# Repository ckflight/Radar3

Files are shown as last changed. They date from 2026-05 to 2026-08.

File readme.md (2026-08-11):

# FMCW3 Hardware Design

Custom 6-layer FPGA-based FMCW radar platform designed in KiCad for high-speed radar acquisition, RF processing, and FPGA DSP applications.

The project integrates:

- RF transmitter and dual receiver chains
- ADL5802 mixer stage
- ADA4940 IF signal conditioning
- LTC2292 high-speed ADC
- Artix-7 FPGA processing
- FT2232H USB FIFO streaming
- Multi-rail low-noise power architecture









---

# Overview

FMCW3 is a custom 5.8 GHz FMCW radar hardware platform built around the Xilinx XC7A35T Artix-7 FPGA.

The board is designed for:

- FMCW radar experiments
- SAR imaging
- Doppler processing
- Phase analysis
- FPGA DSP development
- Radar algorithm research

---

# Main Features

## FPGA

- Xilinx XC7A35T-FTG256
- MicroBlaze soft-core support
- SPI Flash boot
- JTAG debugging
- SD card support
- Parallel ADC interface

## RF Front-End

- HMC431LP4 VCO
- Dual RX channels
- ADL5802 active mixer
- Differential IF architecture
- ADA4940 differential amplifiers

## ADC

- LTC2292 dual-channel ADC
- 12-bit parallel interface
- Differential analog inputs
- FPGA synchronous acquisition

## USB

- FT2232H
- FT245 synchronous FIFO mode
- USB Type-C
- High-speed radar data streaming

---

# 6-Layer PCB Design

The board is designed as a controlled impedance 6-layer RF PCB.

## RF Transmission Line Rules

### Single-Ended 50Ω

- JLCPCB:
  - 0.156 mm trace width
- CST Simulation:
  - 0.17 mm trace width

### Differential 50Ω

- 0.4 mm differential pair width/spacing

### USB Differential Pair

- Target impedance:
  - 90Ω differential
- 0.23 mm width
- 0.13 mm spacing

Results:
- ~100Ω on Oshpark
- ~85Ω on JLCPCB

Accepted as operational for USB HS routing.

---

# RF Layout Notes

- Ground pour kept at least:
  - 3× substrate height away from RF traces
- Via stitching placed:
  - ~1 mm beside RF traces
  - ~0.6 mm from trace edge
- LO path uses smooth bends for impedance continuity
- ADC and IF lengths matched for improved phase consistency
- RF clearances and differential routing optimized
- Differential RF routing corrected for proper 50Ω behavior

---

# KiCad Project Structure

```text
FMCW3/
├── fpga.kicad_sch
├── adc.kicad_sch
├── usb.kicad_sch
├── power.kicad_sch
├── mixer.kicad_sch
├── if.kicad_sch
├── tx.kicad_sch
├── rx.kicad_sch
├── fmcw3.kicad_sch
├── fmcw3.kicad_pcb
└── README.md
```

---

# Design Targets

| Parameter | Value |
|---|---|
| Radar Type | FMCW |
| Frequency | 5.8 GHz |
| FPGA | XC7A35T |
| ADC | LTC2292 |
| Mixer | ADL5802 |
| IF Amplifier | ADA4940 |
| USB Interface | FT2232H |
| PCB Stackup | 6 Layer |
| CAD Tool | KiCad 9 |

---

# Related Repositories

FPGA Firmware:
https://github.com/ckflight/FMCW3

Radar Software:
https://github.com/ckflight/FMCW_RADAR

https://github.com/ckflight/FMCW_RADAR_2v2

AI Radar Experiments:
https://github.com/ckflight/RADAR_24GHZ_NEURAL_NETWORK

---

# Author

Cenk KESKİN

---

# License

This project is licensed under the GNU General Public License v3.0 (GPLv3).

You are free to use, modify, and distribute this software under the terms of the GPLv3 license.

Any distributed modifications or derivative works must also be released under the same license and include source code.

For full license text:

https://www.gnu.org/licenses/gpl-3.0.html

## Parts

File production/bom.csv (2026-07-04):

Designator | Footprint | Quantity | Value | LCSC Part #
C1, C108, C115, C116, C120, C121, C122, C123, C15, C152, C153, C154, C158, C159, C160, C161, C17, C18, C2, C207, C21, C210, C211, C212, C219, C221, C223, C224, C225, C23, C24, C25, C252, C27, C30, C301, C302, C4, C41, C43, C49, C58, C6, C63, C73, C74, C75 | SMD_0402 | 47 | 100n
C10, C13, C36 | SMD_0402 | 3 | 2.2n
C100, C101, C102, C106, C162, C248, C26, C303, C306, C60, C61, C62, C64, C70, C71, C76, C77, C78, C79, C80, C81, C82, C83, C84, C85, C86, C87, C88, C93, C94, C98 | SMD_0805 | 31 | 10u
C103, C104, C32 | SMD_0805 | 3 | DNP
C109, C11, C110, C111, C112, C113, C114, C3, C300, C44, C5, C53, C7, C8 | SMD_0402 | 14 | 10p
C117, C118, C119, C163, C164, C165, C166, C167, C168, C180, C213 | SMD_0402 | 11 | 100p
C12, C19, C20, C217, C218, C222, C249, C89 | SMD_0603 | 8 | 1u
C14, C304, C305, C307 | SMD_0402 | 4 | 220p
C155, C156, C157, C183, C185, C186, C188, C194, C195 | SMD_0603 | 9 | 4.7u
C16, C179, C206, C28, C37, C38, C9, C95 | SMD_0402 | 8 | 10n
C170, C171, C187, C189, C190, C191, C192, C193, C197, C198, C199, C200, C201, C202, C203, C204, C205, C250, C251, C96, C97, C99 | SMD_0402 | 22 | 470n
C181 | SMD_1210 | 1 | 100u
C182, C184, C196 | SMD_1206 | 3 | 47u
C208, C209 | SMD_0402 | 2 | 15p
C216, C22, C220, C31 | SMD_0603 | 4 | 2.2u
C29, R10, R50, R69 | SMD_0402 | 4 | DNP
C33, C34, C39, C40 | SMD_0402 | 4 | 5p
C42, C46, C52, C55 | SMD_0402 | 4 | 18p
C48, C57 | SMD_0402 | 2 | 0.5p
CON1 | DM3BT-DSF-PEJS | 1 | SD_Card_DM3BT
CON2 | BarrelJack | 1 | BARREL_JACK
D1, D2, D3, D5, D6, D7 | Diode_0603 | 6 | LED
F1, F2 | RF_via | 2 | Via
FB1, FB12, FB13, FB14, FB2, FB3, FB4, FB5, FB6, FB7, FB8 | SMD_0603 | 11 | BLM18PG181SN1D
FB11 | SMD_0805 | 1 | MPZ2012S101AT000
J1 | USB_C_Receptacle_GCT_USB4105-xx-A_16P_TopMnt_Horizontal | 1 | USB_C_Receptacle_USB2.0
J2 | PinHeader_2x8_P2.5mm | 1 | Connector_02x08
L1, L3 | SMD_0402 | 2 | LQW15AN9N9J80D
L12, L13, L14, L15 | SMD_0805 | 4 | 2.2u
L2, L4 | SMD_0402 | 2 | 0.6n
L5, L6, L7 | SRR6040A | 3 | 33u (SRR6040A-330M)
P1, P2, U15 | CONSMA003.062 | 3 | SMA
P5, P7, P8 | MountingHole_3.2mm_M3_Pad_Via_mod | 3 | CONN_01X01
R1 | SMD_0402 | 1 | 5.49k
R100, R17, R51, R52, R53, R54, R97, R98, R99 | SMD_0402 | 9 | 49.9
R104, R29, R30, R39, R40, R73, R83, R92 | SMD_0402 | 8 | 10k
R109, R111, R24, R25, R27, R300, R301, R4, R72 | SMD_0402 | 9 | 1k
R11, R12, R9 | SMD_0402 | 3 | 16.9
R110, R114, R115, R18, R19, R20, R41, R42, R55, R56, R57, R58, R63, R64, R7, R70, R80, R81, R93 | SMD_0402 | 19 | 0
R112, R117, R118, R14, R5, R6, R82, R91 | SMD_0402 | 8 | 4.7k
R13, R130, R15, R16, R21, R84, R85, R88 | SMD_0402 | 8 | 33
R2, R48 | SMD_0402 | 2 | 3.3K
R22, R23 | SMD_0402 | 2 | 100
R26, R28, R31, R38 | SMD_0402 | 4 | 500
R3, R8 | SMD_0402 | 2 | 5.1k
R302 | SMD_0402 | 1 | 27
R303, R305 | SMD_0603 | 2 | 2
R304 | SMD_0402 | 1 | 27.4k
R32 | SMD_0402 | 1 | 68k
R33, R34, R36 | SMD_0402 | 3 | 100k
R35, R46, R47 | SMD_0402 | 3 | 18.7K
R37, R71 | SMD_0402 | 2 | 12k
R43 | SMD_0402 | 1 | 18k
R44, R49 | SMD_0402 | 2 | 2k
R45 | SMD_0402 | 1 | 49.9k
R79 | SMD_0402 | 1 | 2.2k
SW1, SW2 | EVP-AWBA2A | 2 | B3U-1000P
U1 | VFQFN-24 | 1 | ADF4158
U10 | VQFN-24 | 1 | HMC431LP4
U11, U16 | XFDFN-6 | 2 | SKY65404
U12 | PAT1220 | 1 | PAT1220-3dB
U13, U9 | DFN-8-1EP_2x2mm_Pitch0.5mm | 2 | TRF37A73
U14 | QFN-20-1EP_4x4mm_P0.5mm_EP2.5x2.5mm_ThermalVias | 1 | TQP5525
U17, U18, U19 | SOT23_6 | 3 | LMR51420
U2, U31, U34, U35, U38, U4, U41, U42, U43, U44, U46, U47, U48, U49, U5 | SolderPad_1_1.0mm_SMD_Circle | 15 | SolderPad_1_Circle
U20, U39 | SOT-23-5 | 2 | LP5907-3.0
U21 | SOT-23-5 | 1 | LP2985A-10DBVR
U22, U23, U24 | DFN-8-1EP_4x4mm_P0.8mm_EP2.3x3.24mm | 3 | LD3920
U25 | DFN-6-1EP_3x3mm_P0.95mm_EP1.7x2.6mm | 1 | LD3920_33
U26, U27, U28 | 5400BL15B050E | 3 | 5400BL15B0050001E
U29 | QFN-24-1EP_4x4mm_Pitch0.5mm | 1 | ADL5802
U3 | PAT1220 | 1 | PAT1220-6dB
U30 | FTG256 | 1 | XC7A35T-1FTG256C
U32 | SOT-23-6 | 1 | 93LC46B
U33 | LQFP-64_10x10mm_Pitch0.5mm | 1 | FT2232H
U36 | SolderPad_1_1.5mm_SMD_Circle | 1 | SolderPad_1_Circle
U40 | DFN-S-8-1EP_6x5mm_Pitch1.27mm | 1 | W25Q128JV
U45 | SSOP16_3.9x4.9mm_P0.635mm | 1 | LT6232
U6 | SOT23_6 | 1 | PL133-37
U7 | SOT-353_SC-70-5 | 1 | TLV172DCK
U8 | QFN-64-1EP_9x9mm_Pitch0.5mm | 1 | LTC2292
Y1 | ABM10 | 1 | ABM10-167-12.000MHZ-T3
Y2 | Oscillator_SMD_ECS_2520MV-xxx-xx-4Pin_2.5x2.0mm | 1 | ECS ECS-TXO-32CSMV-400
Z1 | Directional_Coupler_15dB_0.169mm_v2 | 1 | 15dB COUPLER

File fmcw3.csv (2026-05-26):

Qty | Value | Footprint
49 | 100n | Footprints:SMD_0402
18 | 10p | Footprints:SMD_0402
3 | 2.2n | Footprints:SMD_0402
8 | 1u | Footprints:SMD_0603
4 | 220p | Footprints:SMD_0402
4 | 2.2u | Footprints:SMD_0603
30 | 10u | Footprints:SMD_0805
8 | 10n | Footprints:SMD_0402
30 | DNP | Footprints:SMD_0402
8 | DNP | Footprints:SMD_0603
4 | 18p | Footprints:SMD_0402
2 | 0.5p | Footprints:SMD_0402
13 | DNP | Footprints:SMD_0805
22 | 470n | Footprints:SMD_0402
11 | 100p | Footprints:SMD_0402
9 | 4.7u | Footprints:SMD_0603
1 | 100u | Footprints:SMD_1210
3 | 47u | Footprints:SMD_1206
2 | 15p | Footprints:SMD_0402
1 | SD_Card_DM3BT | fmcw3:DM3BT-DSF-PEJS
1 | BARREL_JACK | Footprints:BarrelJack
6 | LED | Footprints:Diode_0603
11 | BLM18PG181SN1D | Footprints:SMD_0603
1 | MPZ2012S101AT000 | Footprints:SMD_0805
1 | USB_C_Receptacle_USB2.0 | Connector_USB:USB_C_Receptacle_GCT_USB4105-xx-A_16P_TopMnt_Horizontal
2 | LQW15AN9N9J80D | Footprints:SMD_0402
2 | 0.6n | Footprints:SMD_0402
3 | 33u (SRR6040A-330M) | fmcw3:SRR6040A
4 | 2.2u | Footprints:SMD_0805
1 | 5.49k | Footprints:SMD_0402
1 | 3.3K | Footprints:SMD_0402
2 | 5.1k | Footprints:SMD_0402
1 | 1K | Footprints:SMD_0402
8 | 4.7k | Footprints:SMD_0402
16 | 0 | Footprints:SMD_0402
3 | 16.7 | Footprints:SMD_0402
4 | 33 | Footprints:SMD_0402
9 | 49.9 | Footprints:SMD_0402
4 | 22 | Footprints:SMD_0402
2 | 100 | Footprints:SMD_0402
11 | 1k | Footprints:SMD_0402
2 | 68k | Footprints:SMD_0402
3 | 100k | Footprints:SMD_0402
1 | 18.7K | Footprints:SMD_0402
2 | 12k | Footprints:SMD_0402
1 | 18k | Footprints:SMD_0402
2 | 2k | Footprints:SMD_0402
1 | 49.9k | Footprints:SMD_0402
2 | 18.7k | Footprints:SMD_0402
1 | 3.3k | Footprints:SMD_0402
4 | 20.5k | Footprints:SMD_0402
3 | 10k | Footprints:SMD_0402
1 | 2.2k | Footprints:SMD_0402
1 | 240 | Footprints:SMD_0402
1 | 27 | Footprints:SMD_0402
2 | 2 | Footprints:SMD_0603
1 | 27.4k | Footprints:SMD_0402
2 | SW_PUSH | fmcw3:EVP-AWBA2A
1 | ADF4158 | fmcw3:VFQFN-24
1 | PAT1220-6dB | fmcw3:PAT1220
1 | ECS-TXO-3225MV | Oscillator:Oscillator_SMD_EuroQuartz_XO32-4Pin_3.2x2.5mm
1 | NB3N551 | fmcw3:DFN-8
1 | TLV172DCK | TO_SOT_Packages_SMD:SOT-353_SC-70-5
1 | LTC2292 | Housings_DFN_QFN:QFN-64-1EP_9x9mm_Pitch0.5mm
2 | TRF37A73 | fmcw3:DFN-8-1EP_2x2mm_Pitch0.5mm
1 | HMC431LP4 | fmcw3:VQFN-24
2 | SKY65404 | fmcw3:XFDFN-6
1 | PAT1220-3dB | fmcw3:PAT1220
1 | TQP5525 | Package_DFN_QFN:QFN-20-1EP_4x4mm_P0.5mm_EP2.5x2.5mm_ThermalVias
3 | LMR51420 | Footprints:SOT23_6
2 | LP5907-3.0 | fmcw3:SOT-23-5
1 | LP2985A-10DBVR | fmcw3:SOT-23-5
3 | LD3920 | Package_DFN_QFN:DFN-8-1EP_4x4mm_P0.8mm_EP2.3x3.24mm
1 | BU33SD5WG | fmcw3:SOT-23-5
3 | 5400BL15B050E | fmcw3:5400BL15B050E
1 | ADL5802 | Housings_DFN_QFN:QFN-24-1EP_4x4mm_Pitch0.5mm
1 | XC7A35T-1FTG256C | fmcw3:FTG256
1 | 93LC46B | fmcw3:SOT-23-6
1 | FT2232H | Housings_QFP:LQFP-64_10x10mm_Pitch0.5mm
2 | ADA4940-2 | fmcw3:VFQFN-24
1 | W25Q32JV | Housings_DFN_QFN:DFN-S-8-1EP_6x5mm_Pitch1.27mm
1 | ABM10-167-12.000MHZ-T3 | fmcw3:ABM10

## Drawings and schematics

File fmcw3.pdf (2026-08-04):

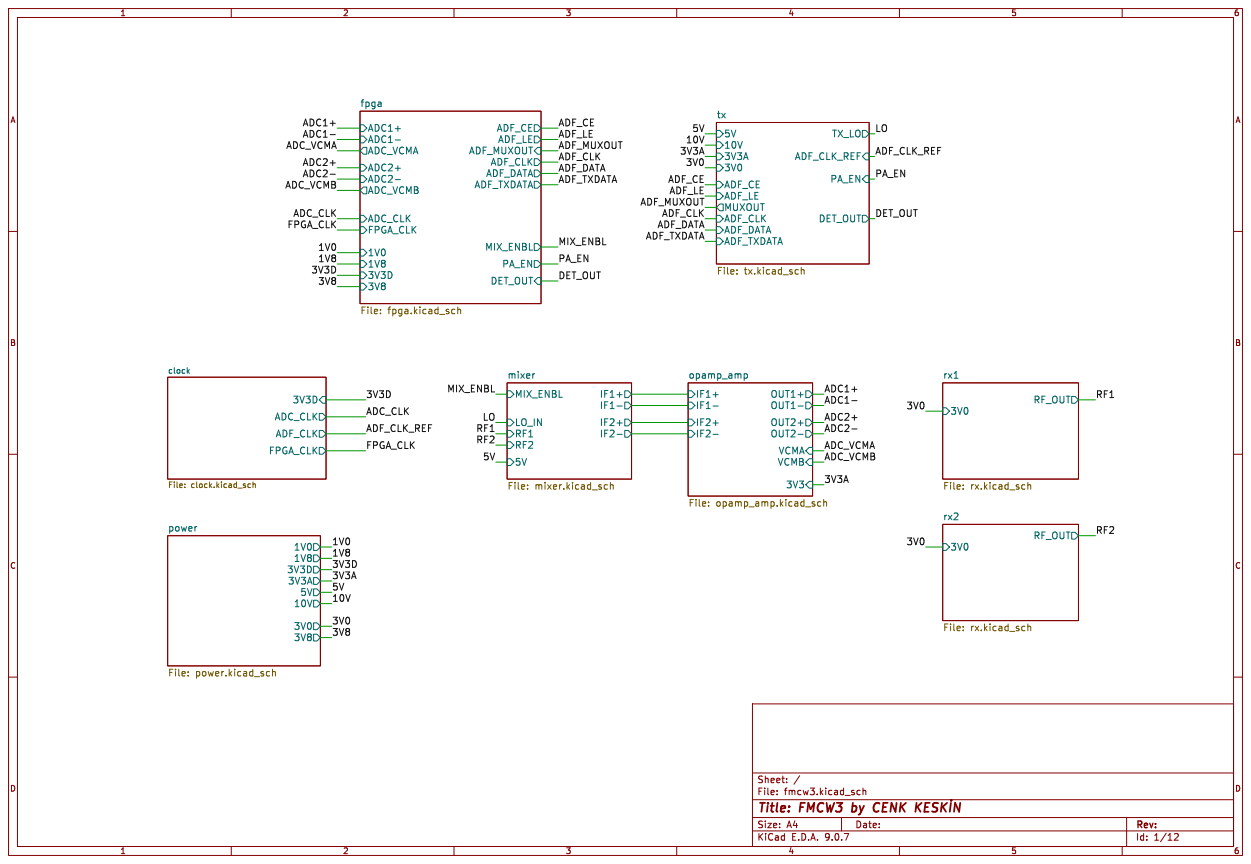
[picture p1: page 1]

File: fmcw3.kicad_sch Sheet: /
Id: 1/12 Title: FMCW3 by CENK þÿKESK0N

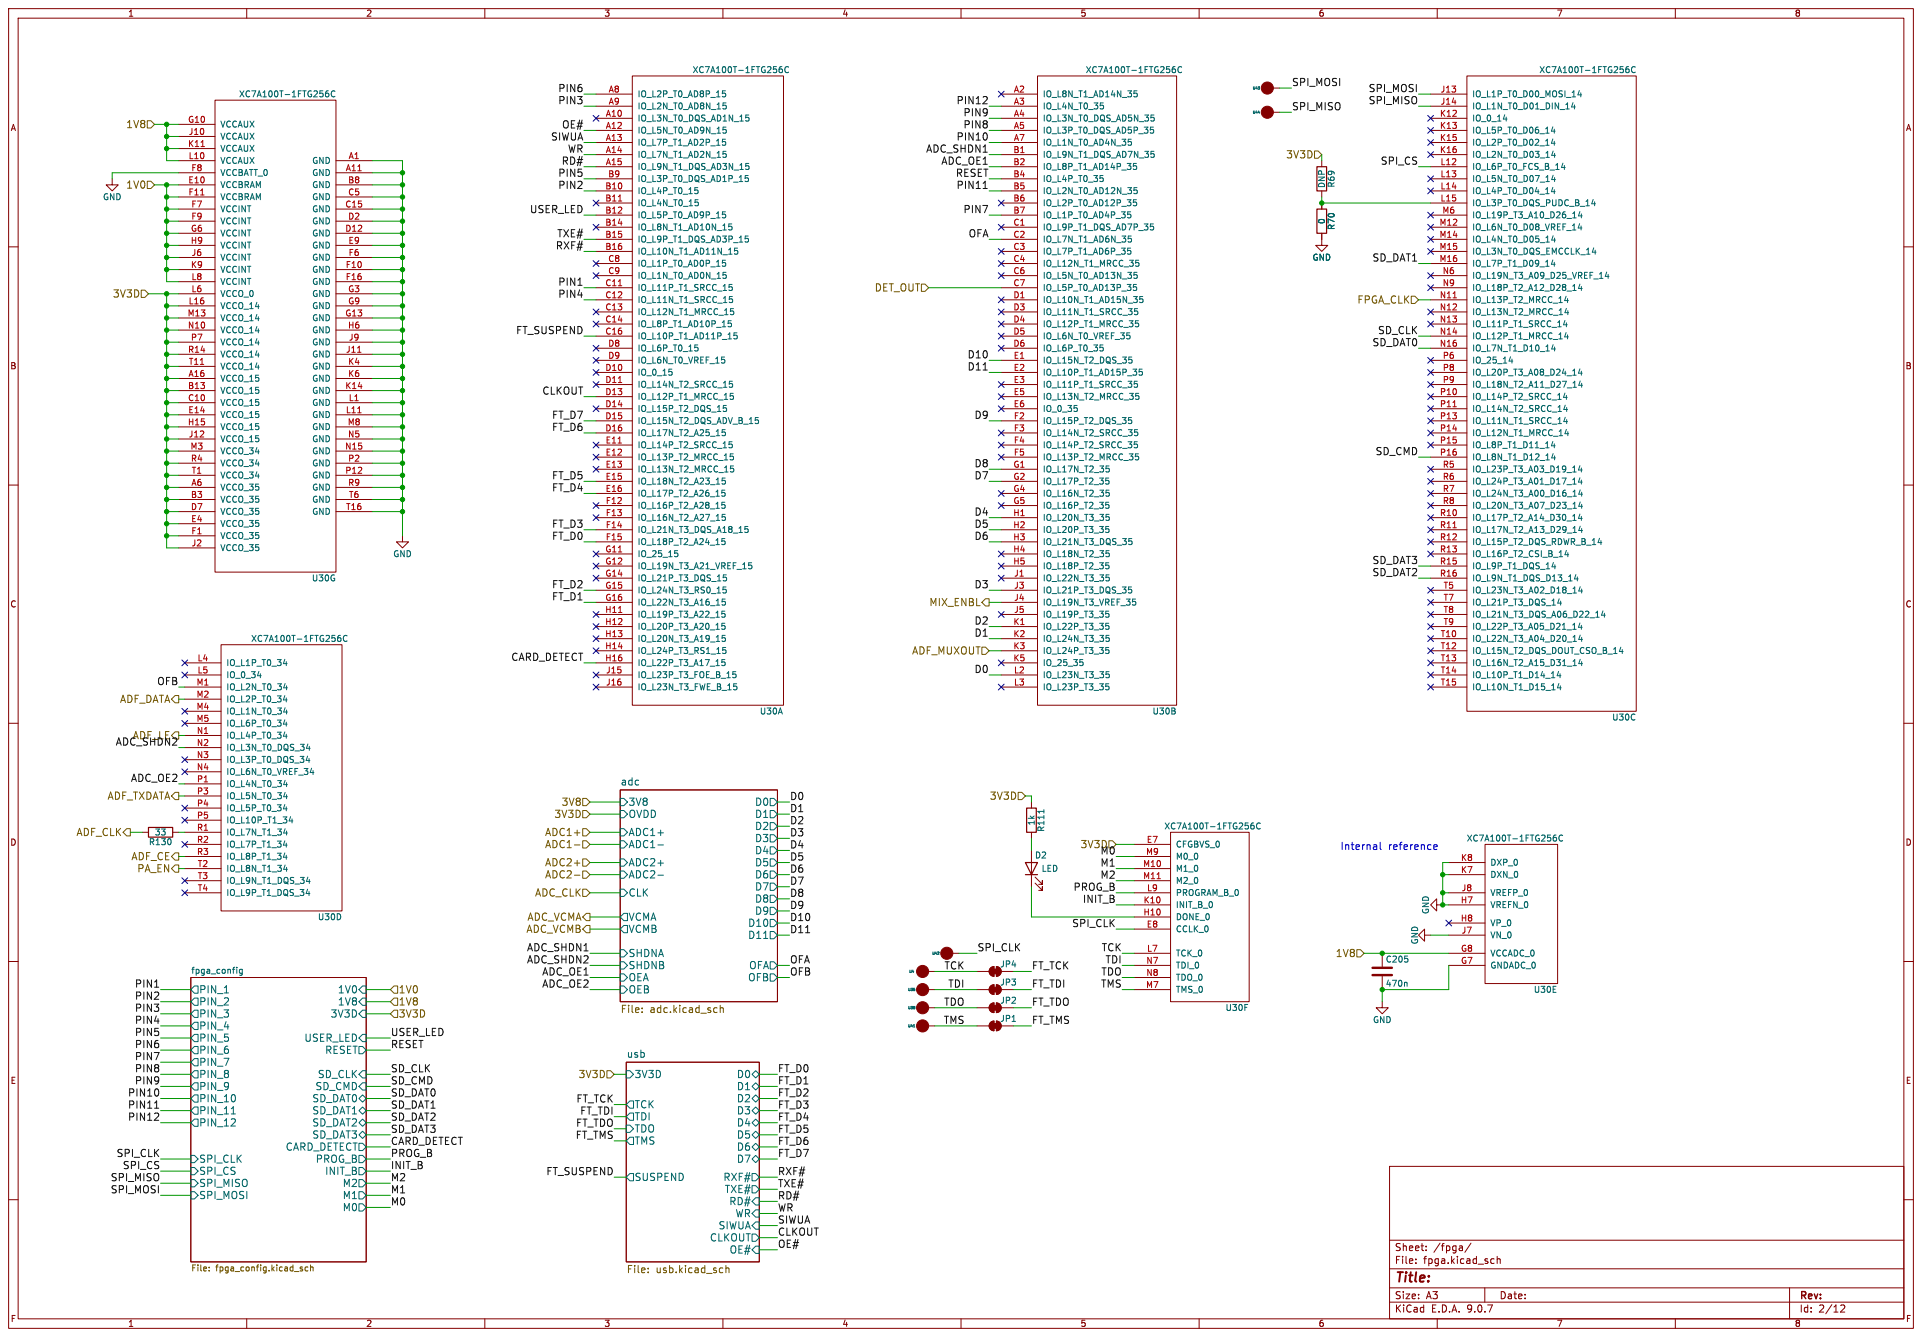
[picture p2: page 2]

PIN3 PIN6 OE# WR
PIN1 PIN4 SIWUA
PIN5 RD# PIN2 TXE# RXF# CLKOUT

SD_DAT3 CARD_DETECT

SIWUA OE#

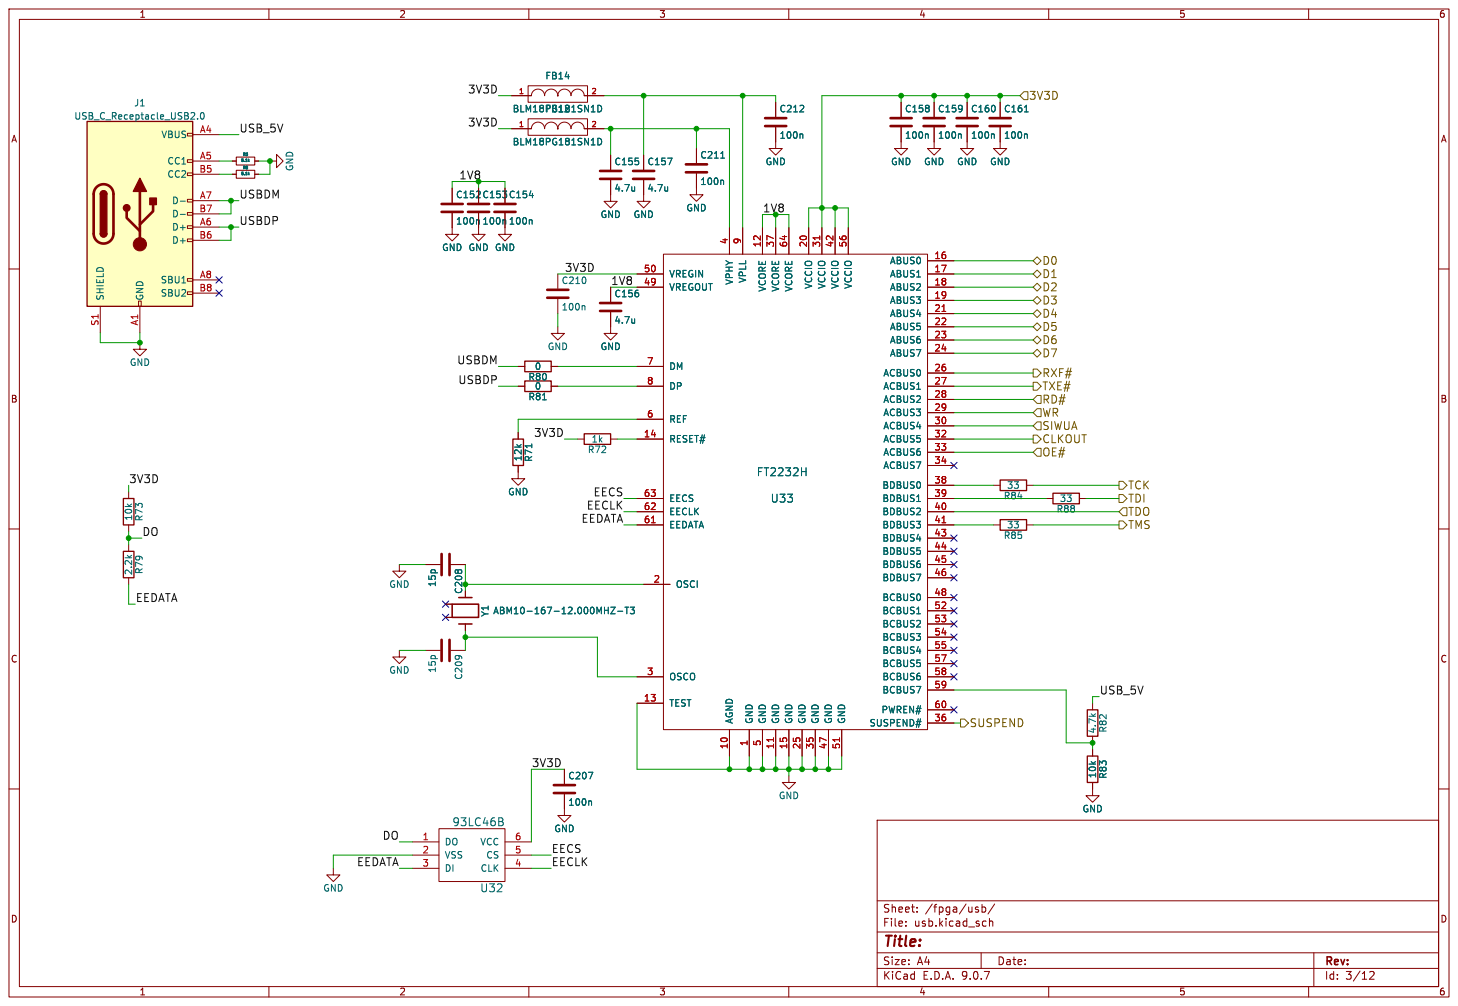
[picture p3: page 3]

Id: 3/12 Title: File: usb.kicad_sch Sheet: /fpga/usb/

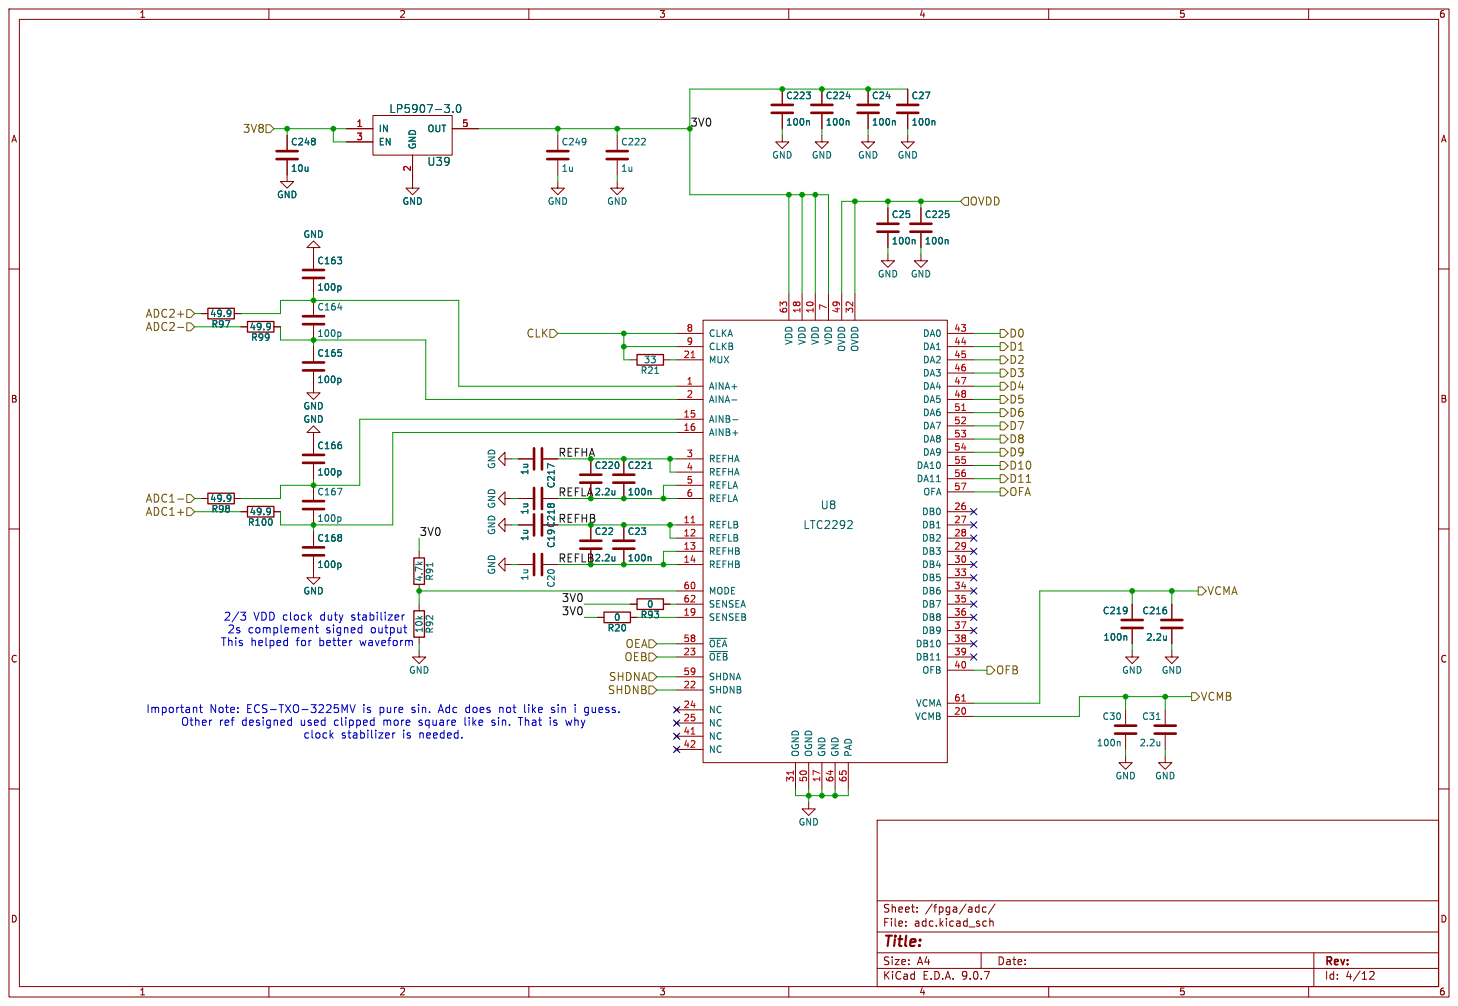
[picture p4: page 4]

7 GND 64 OVDD 49 PAD 65 OVDD 32 DA0 43 DA1 44 DA2 45 DA3 46 DA4 47 DA5 48 DA6 51 DA7 52 DA8 53 DA9 54 DA10 55 DA11 56 OFA 57 DB0 26 DB1 27 DB2 28 DB3 29 DB4 30 DB5 33 DB6 34 DB7 35 DB8 36 DB9 37 DB10 38 DB11 39 OFB 40 VCMA 61 VCMB 20 U8

Other ref designed used clipped more square like sin. That is why

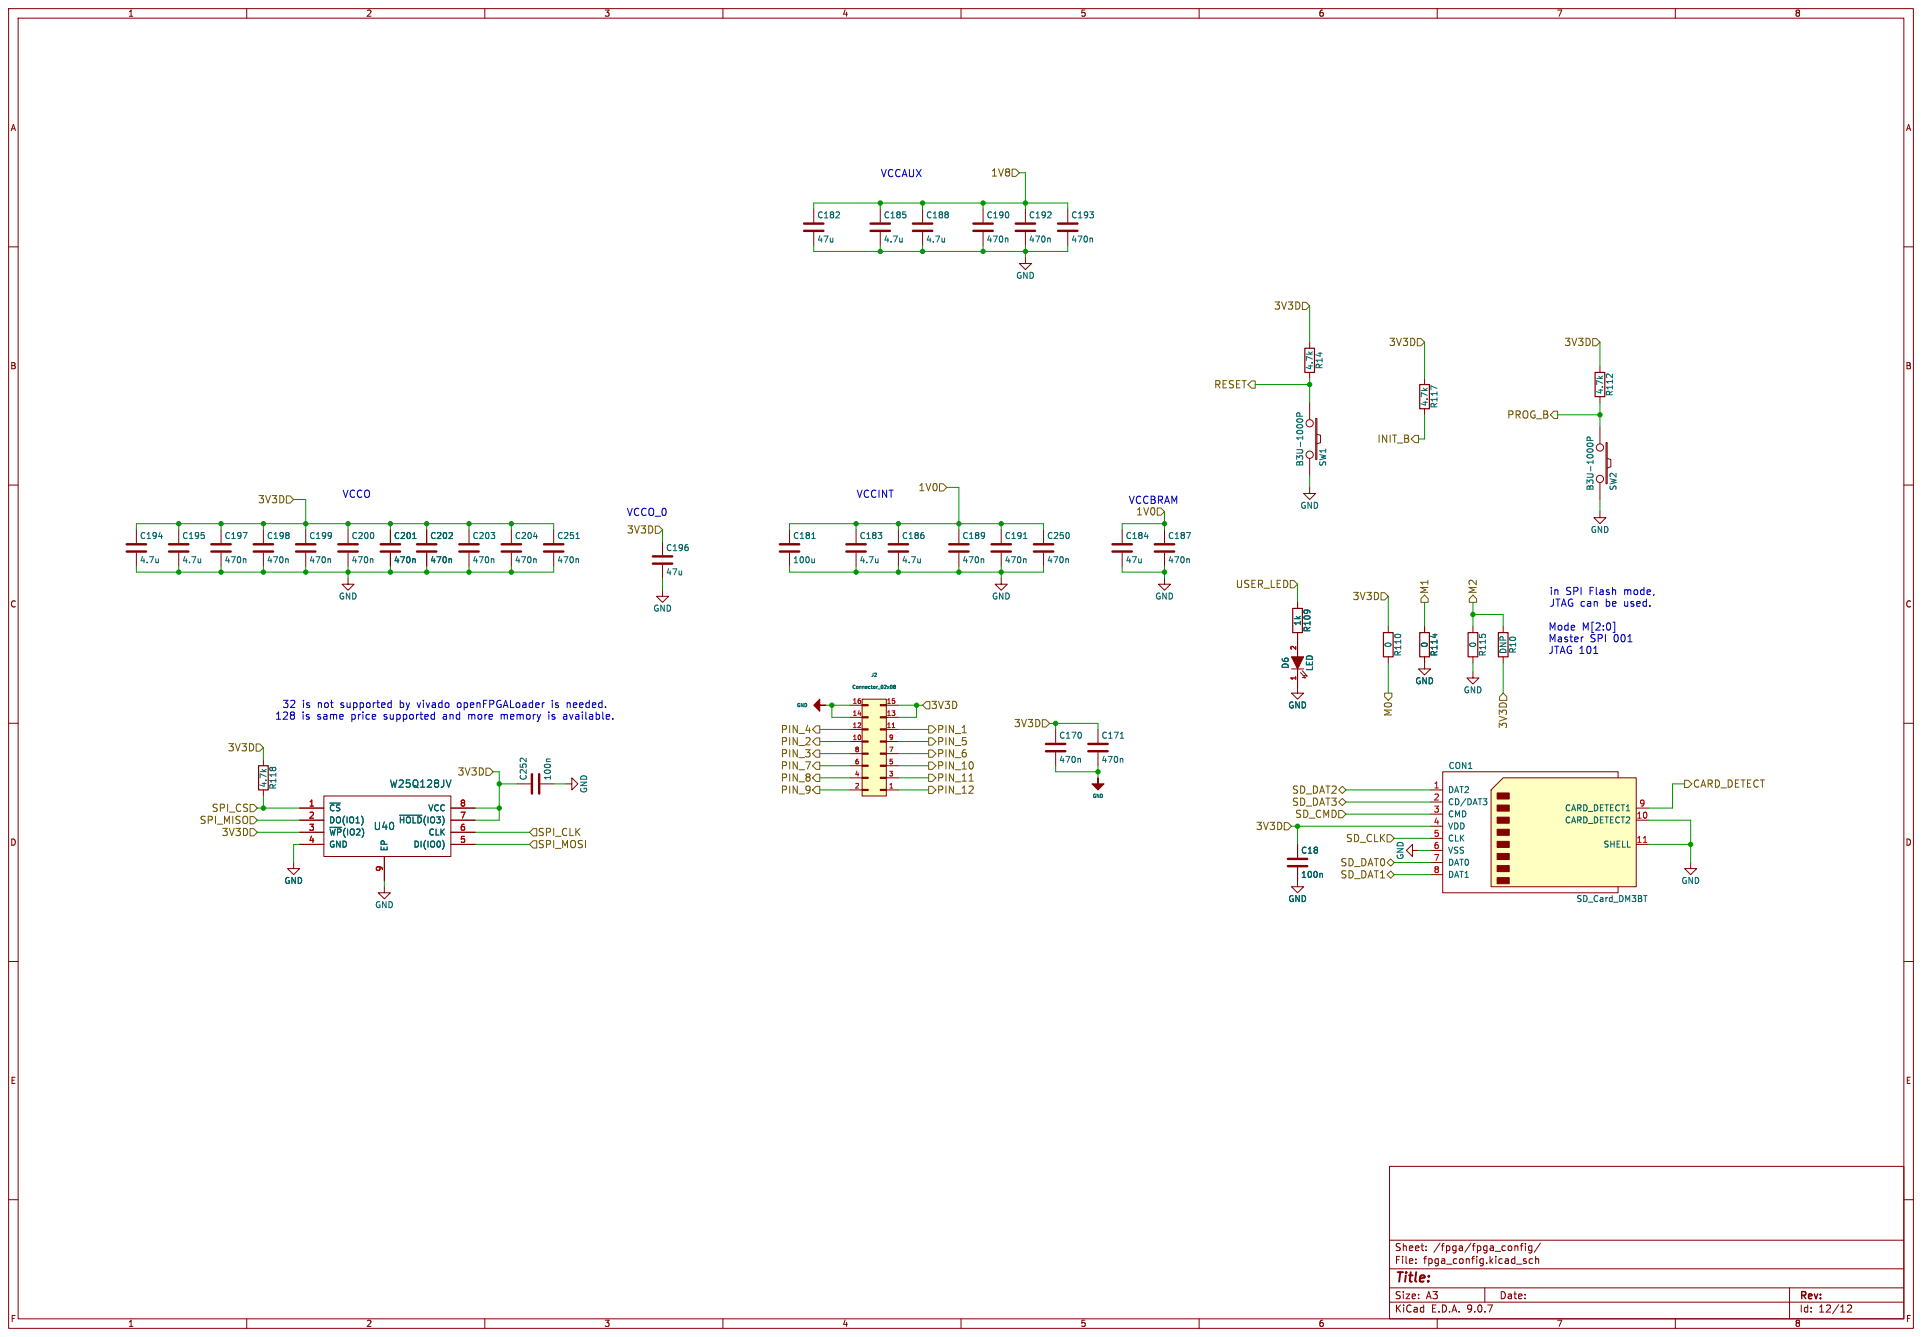
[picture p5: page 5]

9 VCC 8 ~{HOLD}(IO3) 7 CLK 6 DI(IO0) 5 U40W25Q128JV B3U-1000P SW1 GND GND GND

in SPI Flash mode,

9 VCC 8 ~{HOLD}(IO3) 7 CLK 6 DI(IO0) 5 GND

Id: 12/12 Title: File: fpga_config.kicad_sch Sheet: /fpga/fpga_config/

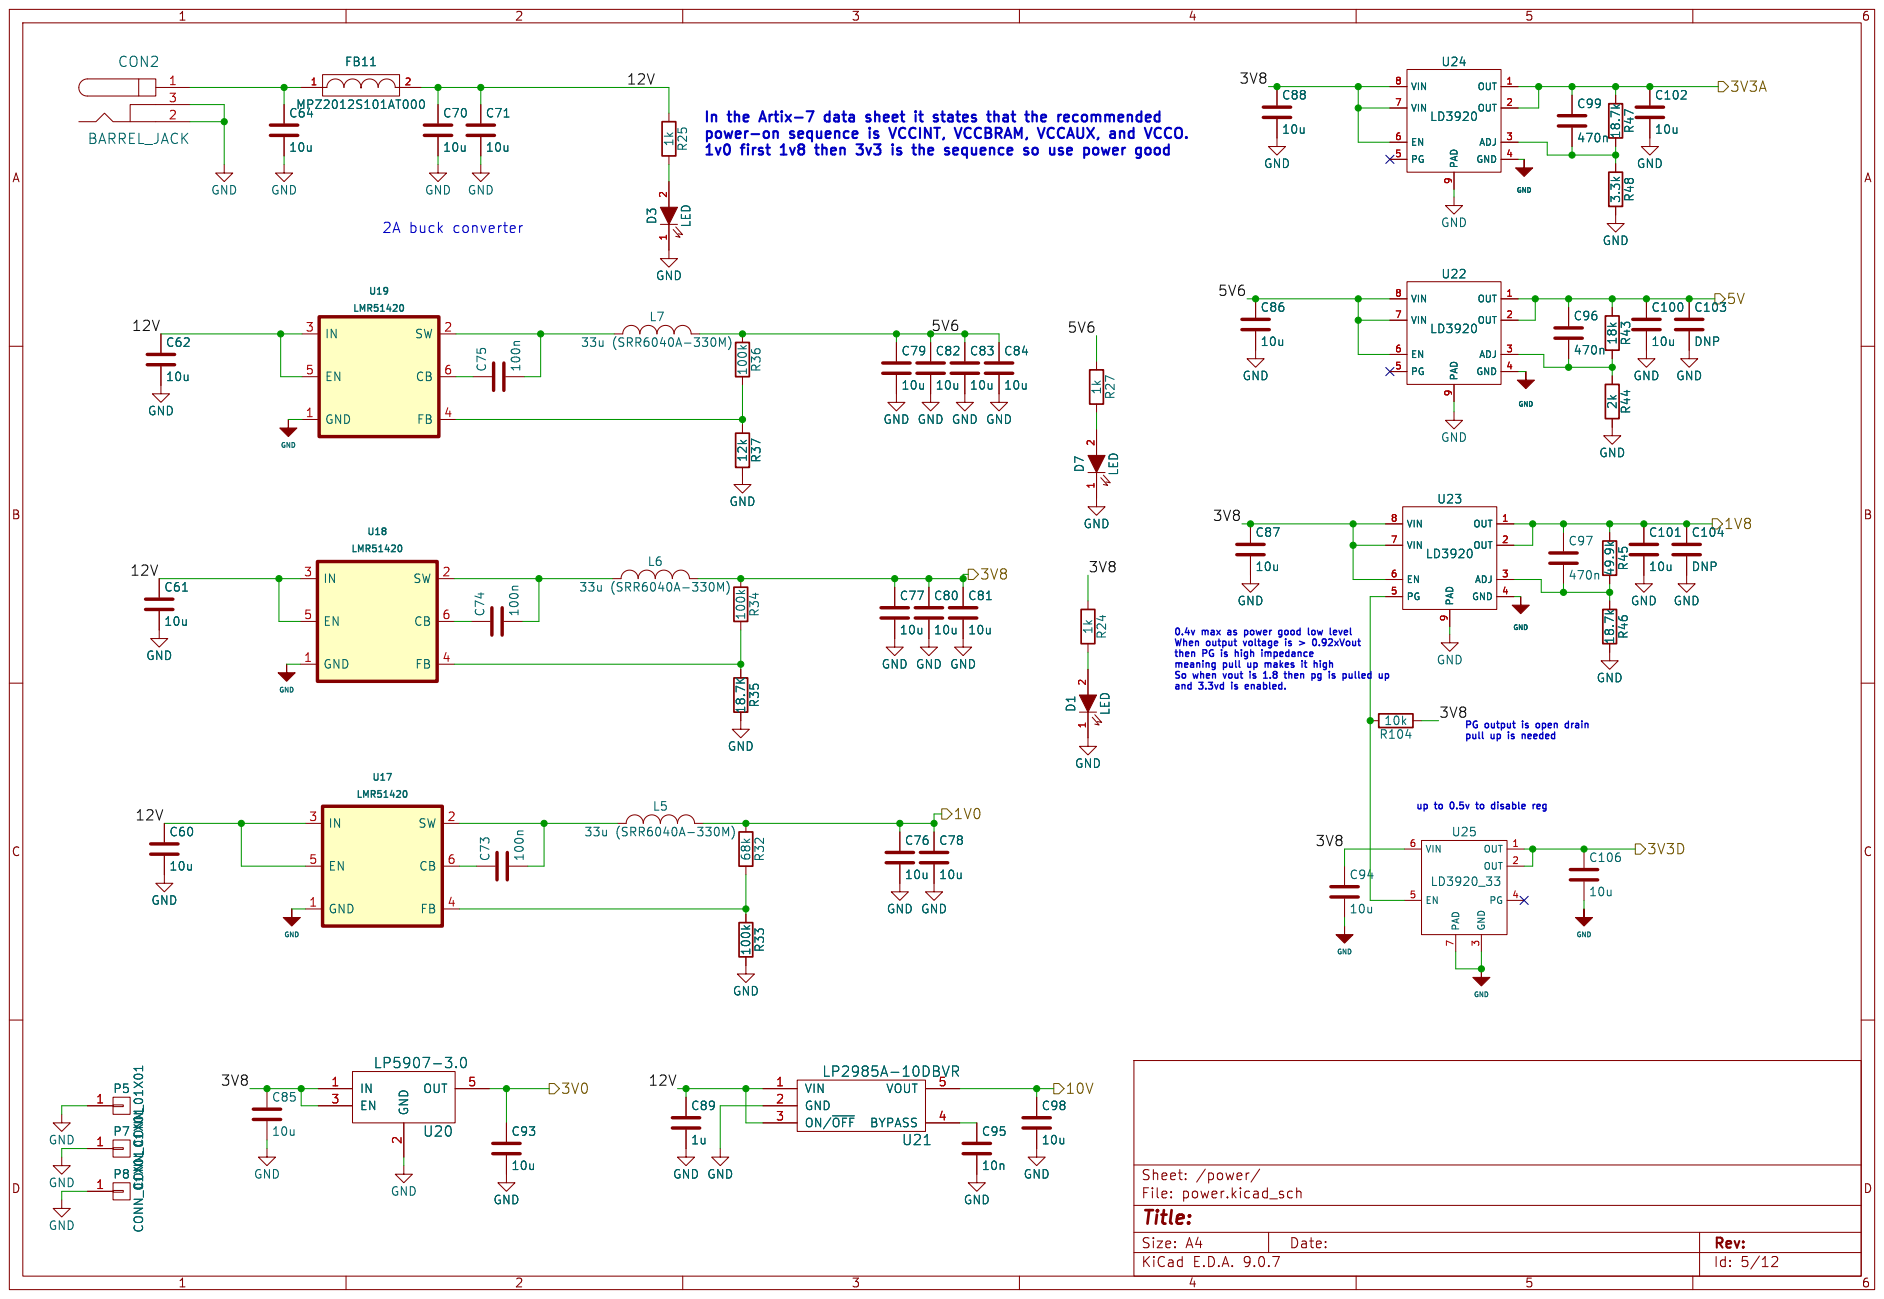
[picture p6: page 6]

9 OUT 1 OUT 2 ADJ 3 GND 4 U24

9 OUT 1 OUT 2 ADJ 3 GND 4

9 OUT 1 OUT 2 ADJ 3 GND 4 U22
LD3920 GND

9 OUT 1 OUT 2 ADJ 3 GND 4 C86

9 OUT 1 OUT 2 ADJ 3 GND 4 U23

10u GND GND GND GND

0.4v max as power good low level When output voltage is > 0.92xVout

then PG is high impedance meaning pull up makes it high So when vout is 1.8 then pg is pulled up

PG output is open drain
pull up is needed

Id: 5/12 Title: File: power.kicad_sch Sheet: /power/

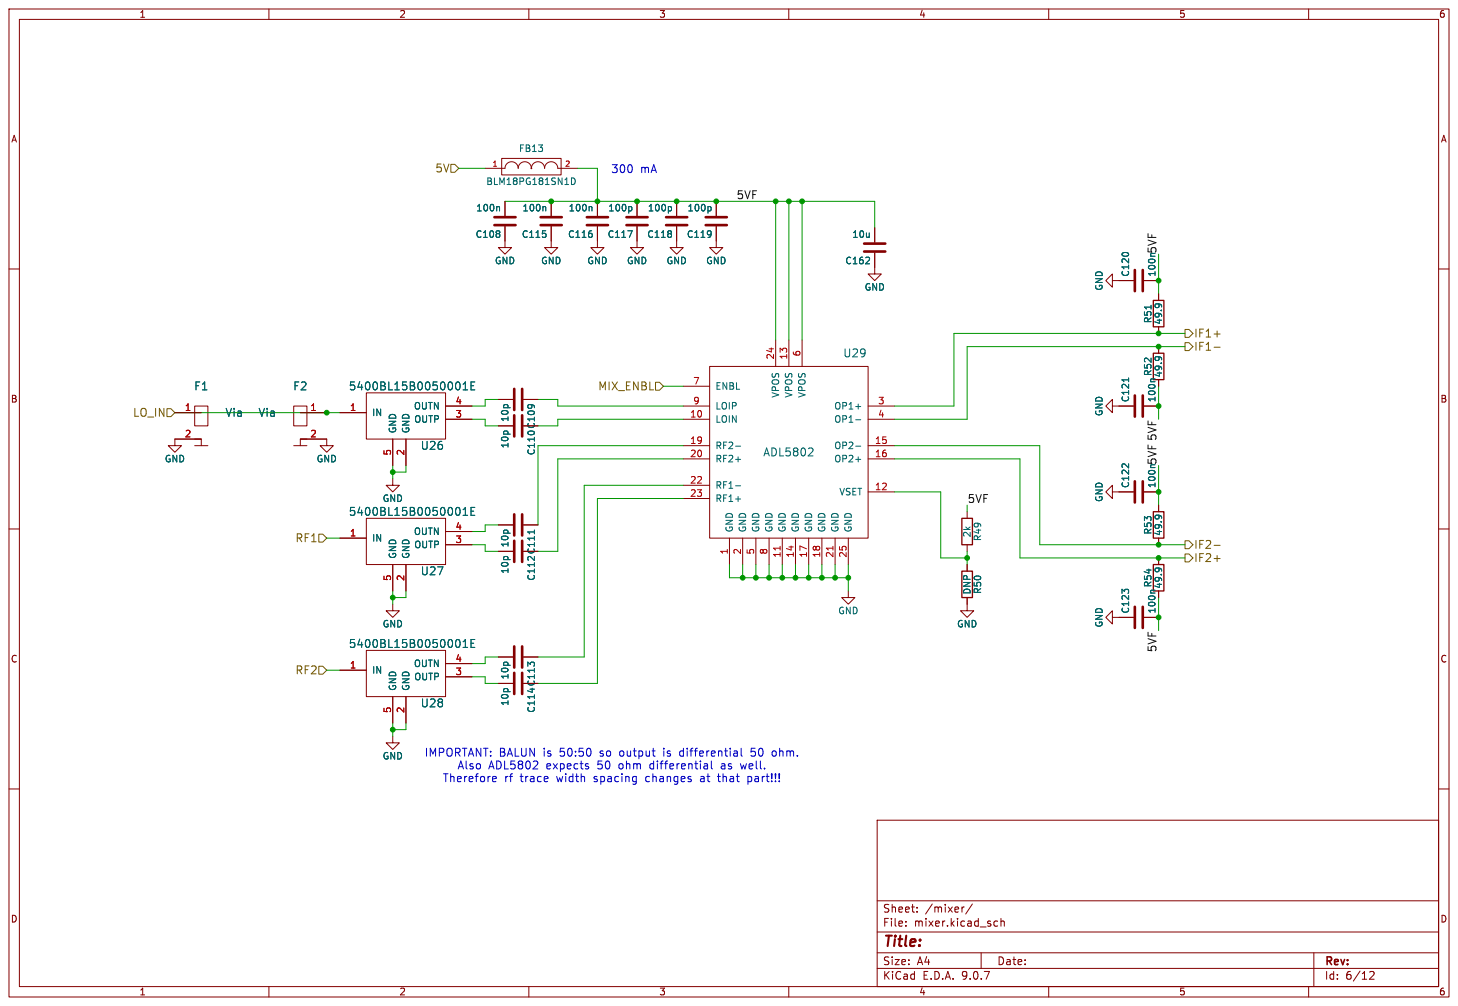
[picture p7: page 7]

2 OUTN 4 OUTP 3 GND GND GND

8 VPOS 24 GND 11 VPOS 13 GND 14 VPOS

6 GND 17 GND 18 GND 21 GND 25 OP1+ 3 OP1- 4 OP2- 15 OP2+ 16 VSET 12 U29 ADL5802

Id: 6/12 Title: File: mixer.kicad_sch Sheet: /mixer/

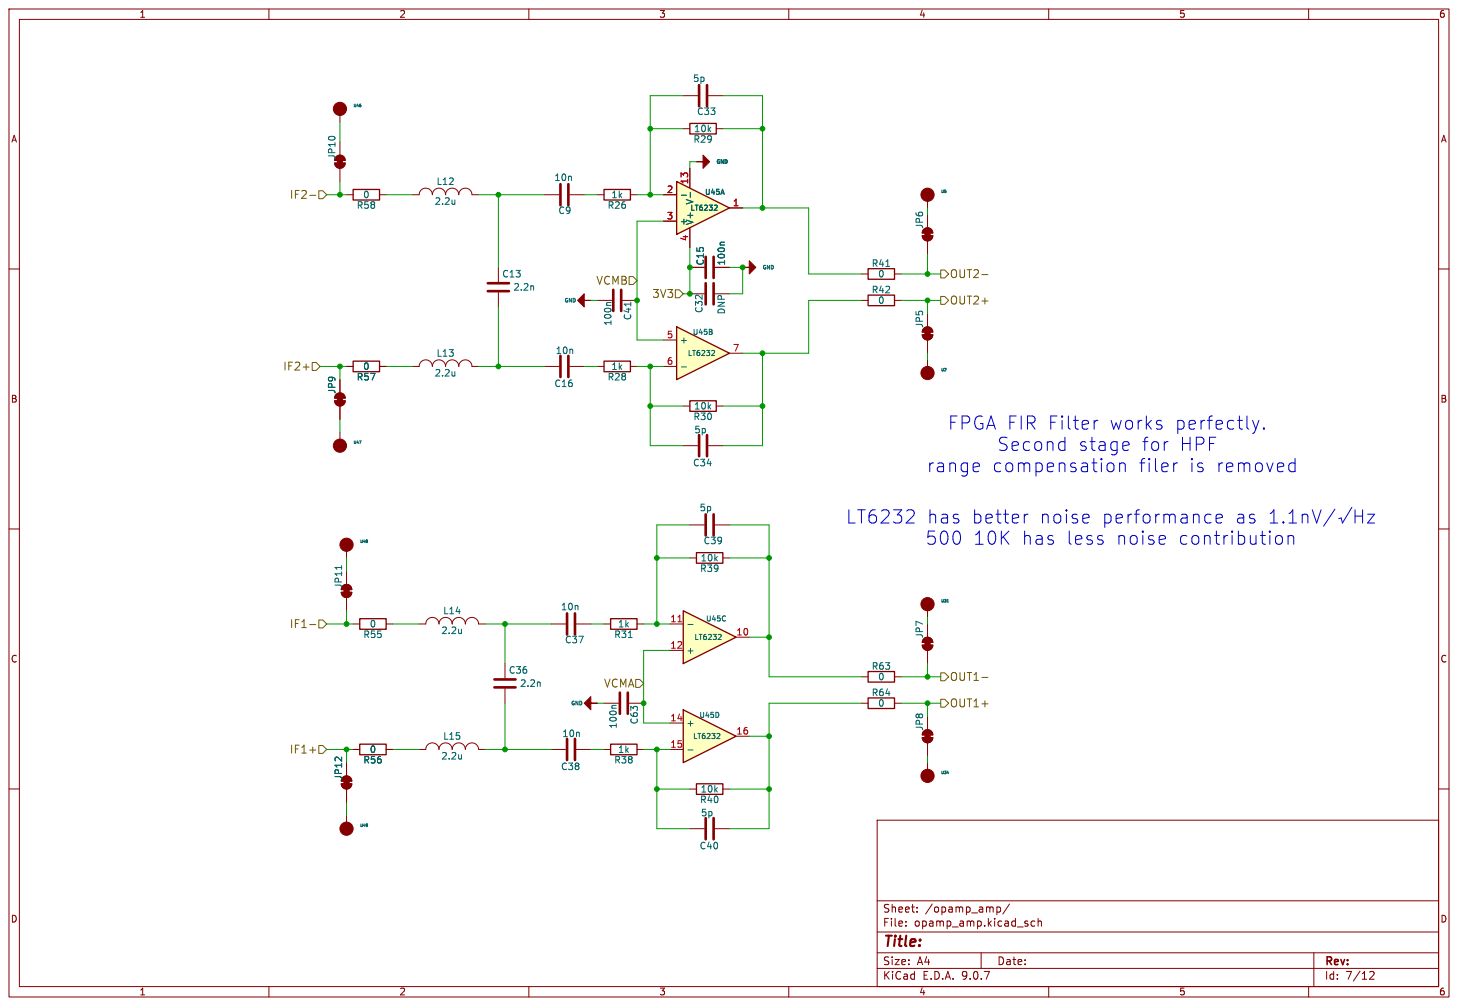
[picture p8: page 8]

Second stage for HPF

500 10K has less noise contribution

Id: 7/12 Title: File: opamp_amp.kicad_sch Sheet: /opamp_amp/

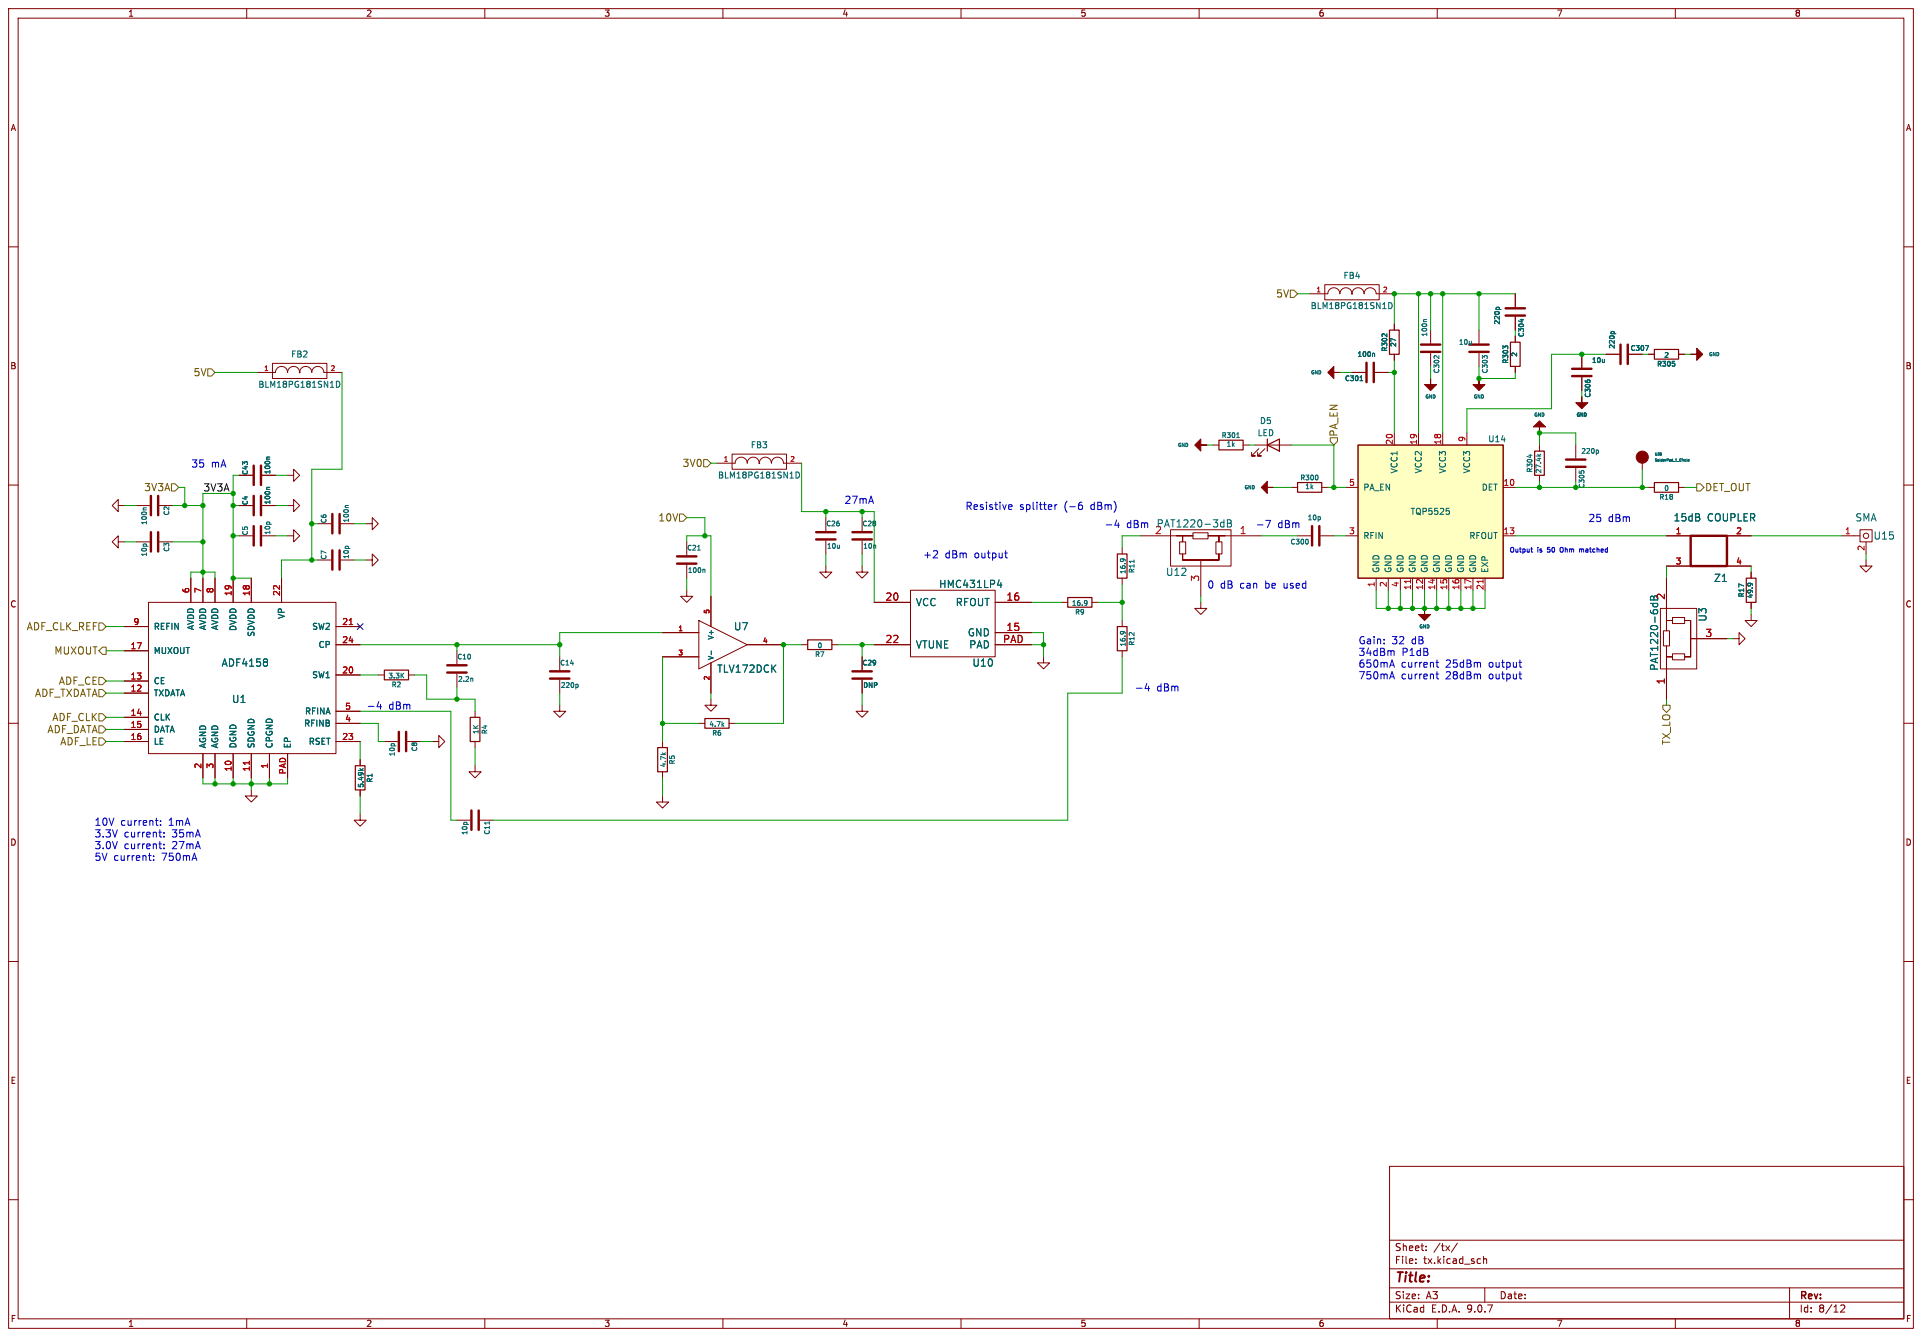
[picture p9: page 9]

9 GND 17 EXP 21 DET 10 RFOUT 13 U14 TQP5525 C28

4 GND 11 VCC2 19 GND 12 GND 14 VCC3 18 GND 15 GND 16 VCC3

Output is 50 Ohm matched 27mA

650mA current 25dBm output 750mA current 28dBm output -4 dBm

3 DVDD 19 DGND 10 SDVDD 18 SDGND 11 CPGND

Id: 8/12 Title: File: tx.kicad_sch Sheet: /tx/

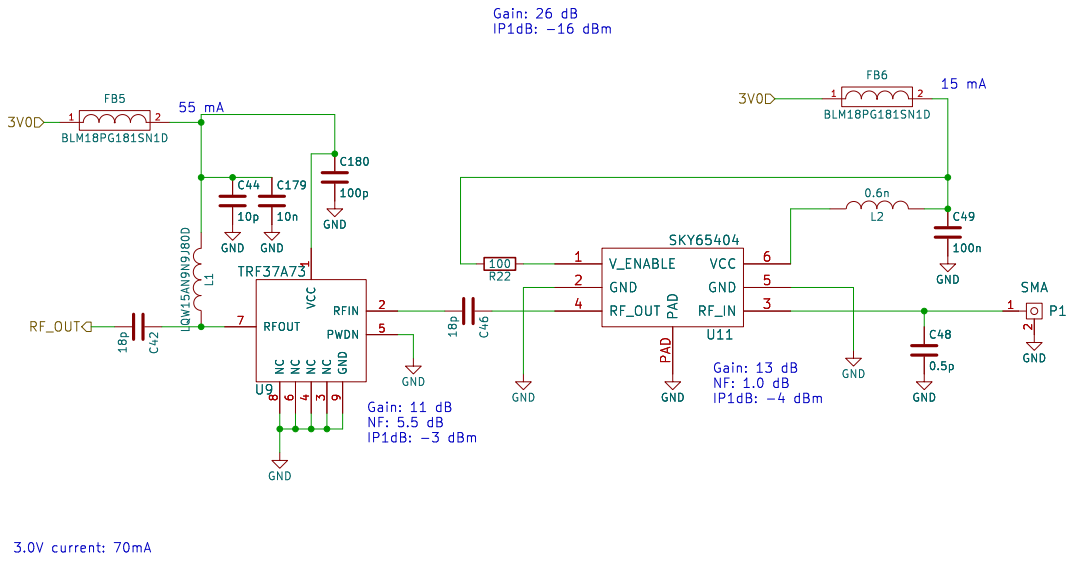
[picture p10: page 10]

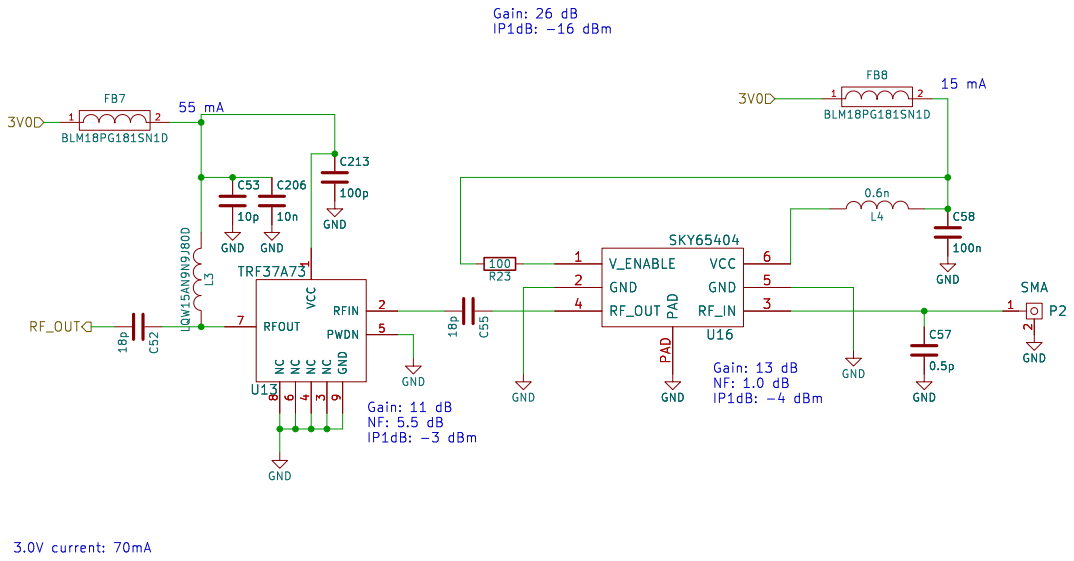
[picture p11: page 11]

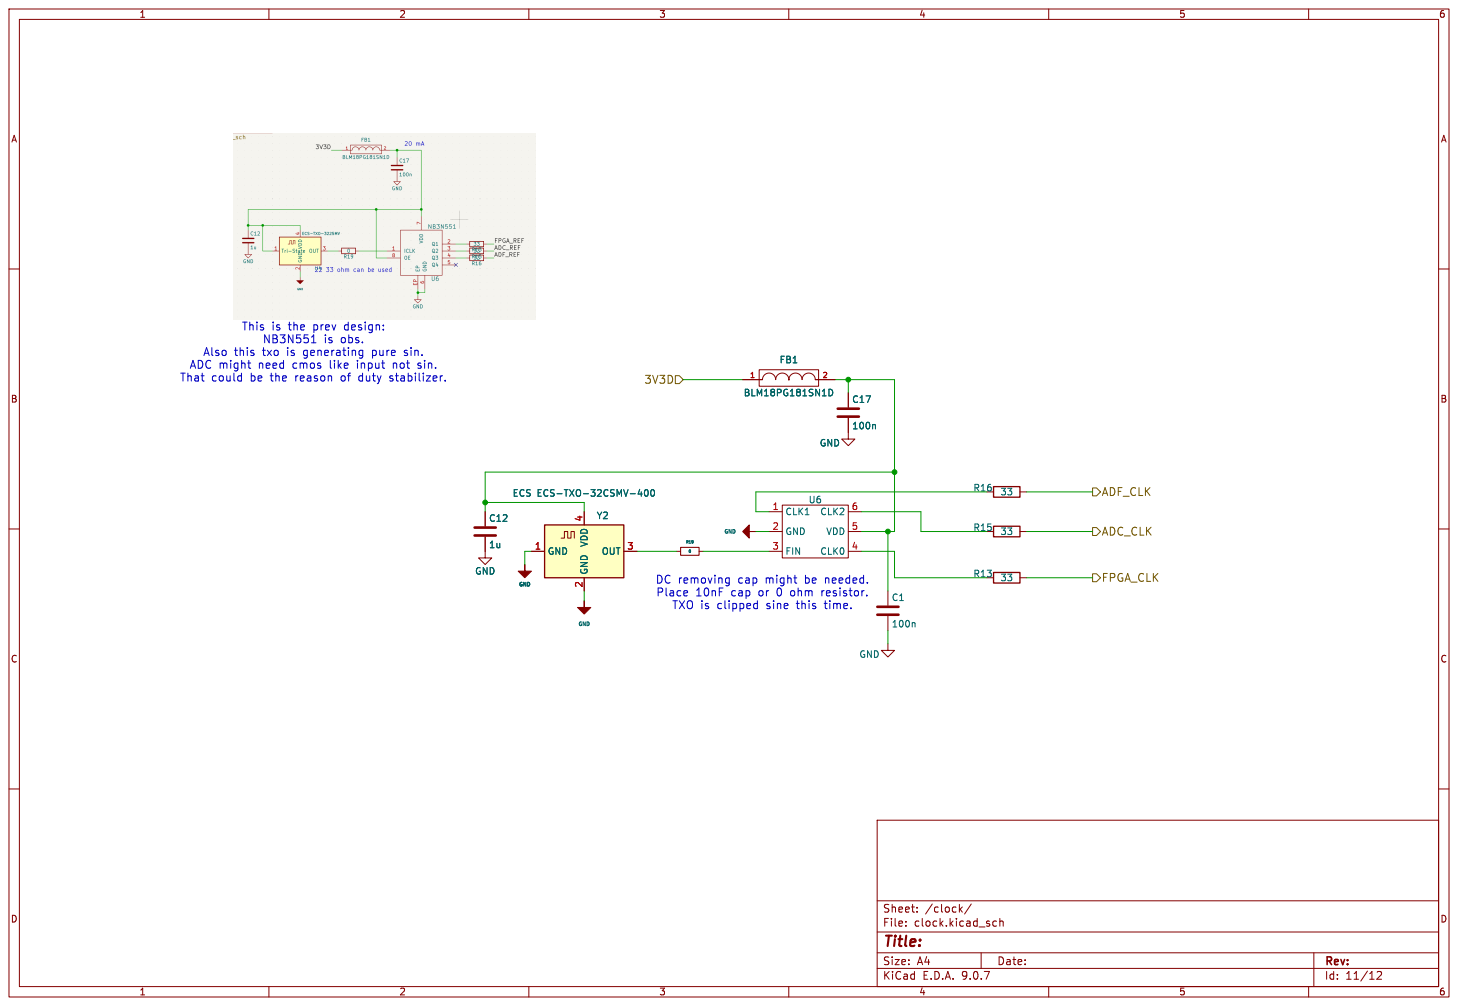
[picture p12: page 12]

2 OUT 3 Y2 ECS ECS-TXO-32CSMV-400

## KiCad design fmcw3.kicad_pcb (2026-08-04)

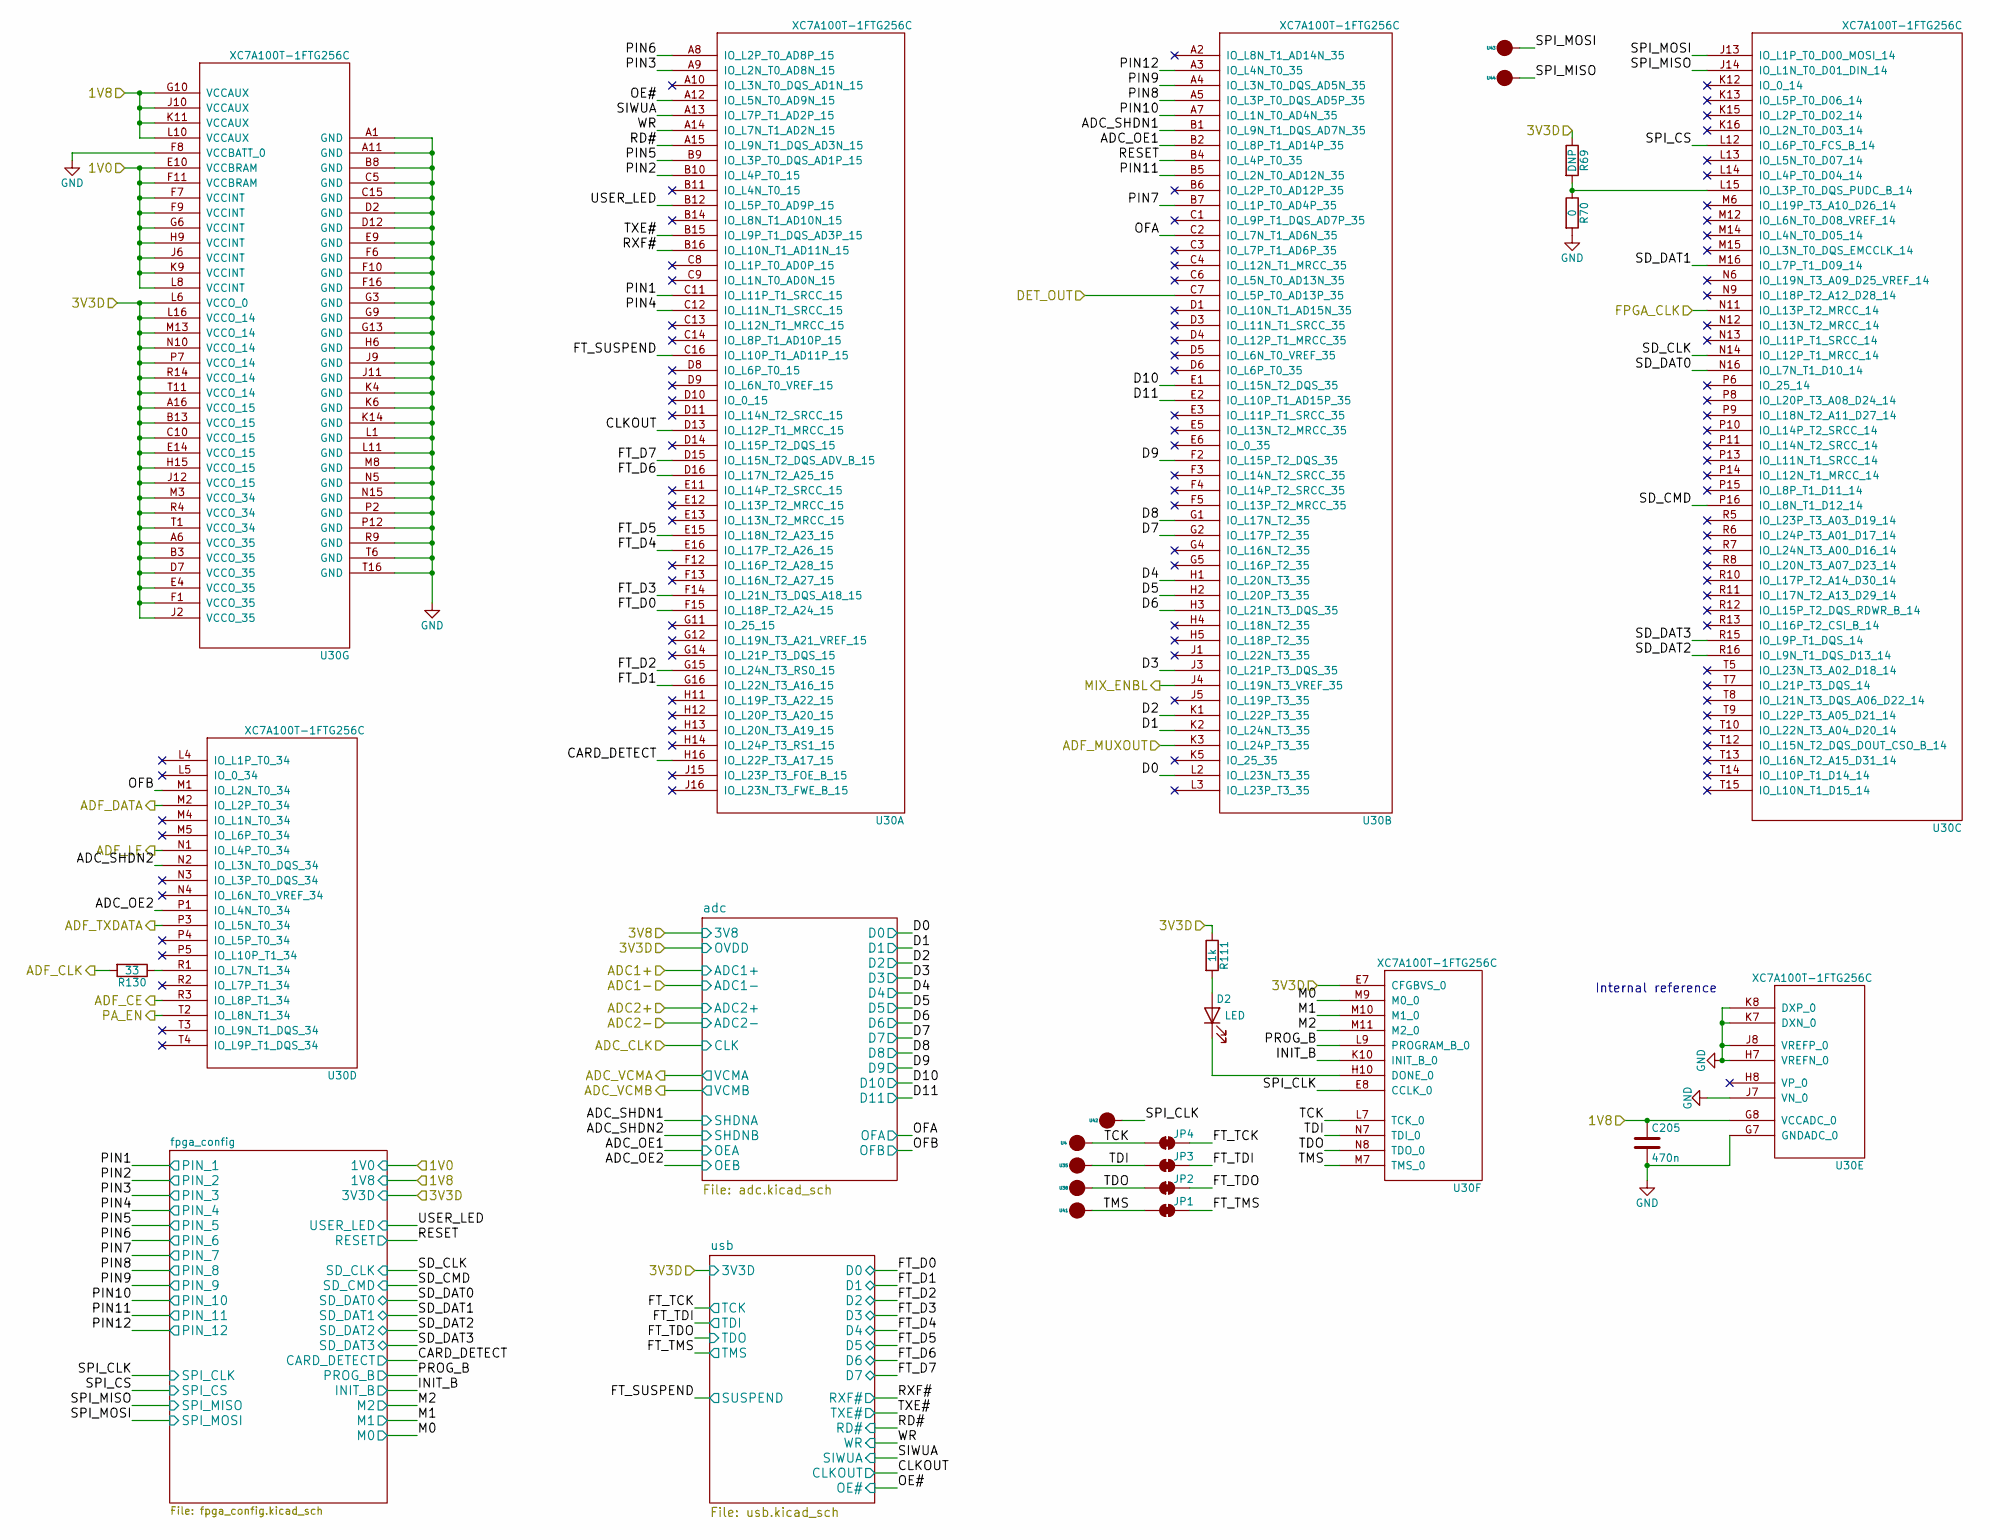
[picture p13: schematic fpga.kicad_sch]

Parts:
C205: 470n; SMD_0402
D2: LED; Diode_0603
JP1, JP2, JP3, JP4: SolderJumper_2_Bridged; SolderPad_2_Bridge
R69: DNP; SMD_0402
R70: 0; SMD_0402
R111: 1k; SMD_0402
R130: 33; SMD_0402
U4, U35, U38, U41, U42, U43, U44: SolderPad_1_Circle; SolderPad_1_1.0mm_SMD_Circle
U30: XC7A100T-1FTG256C; FTG256

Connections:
/1V0: U30.E10 (VCCBRAM), U30.F7 (VCCINT), U30.F9 (VCCINT), U30.F11 (VCCBRAM), U30.G6 (VCCINT), U30.H9 (VCCINT), U30.J6 (VCCINT), U30.K9 (VCCINT), U30.L8 (VCCINT); also elsewhere on the board
/1V8: C205.1, U30.G8 (VCCADC_0), U30.G10 (VCCAUX), U30.J10 (VCCAUX), U30.K11 (VCCAUX), U30.L10 (VCCAUX); also elsewhere on the board
/3V3D: R69.1, R111.1, U30.A6 (VCCO_35), U30.A16 (VCCO_15), U30.B3 (VCCO_35), U30.B13 (VCCO_15), U30.C10 (VCCO_15), U30.D7 (VCCO_35), U30.E4 (VCCO_35), U30.E7 (CFGBVS_0), U30.E14 (VCCO_15), U30.F1 (VCCO_35), U30.H15 (VCCO_15), U30.J2 (VCCO_35), U30.J12 (VCCO_15), U30.L6 (VCCO_0), U30.L16 (VCCO_14), U30.M3 (VCCO_34), U30.M13 (VCCO_14), U30.N10 (VCCO_14), U30.P7 (VCCO_14), U30.R4 (VCCO_34), U30.R14 (VCCO_14), U30.T1 (VCCO_34), U30.T11 (VCCO_14); also elsewhere on the board
/ADF_CE: U30.R3 (IO_L8P_T1_34); also elsewhere on the board
/ADF_CLK: R130.2; also elsewhere on the board
/ADF_DATA: U30.M2 (IO_L2P_T0_34); also elsewhere on the board
/ADF_LE: U30.N1 (IO_L4P_T0_34); also elsewhere on the board
/ADF_MUXOUT: U30.K3 (IO_L24P_T3_35); also elsewhere on the board
/ADF_TXDATA: U30.P3 (IO_L5N_T0_34); also elsewhere on the board
/DET_OUT: U30.C7 (IO_L5P_T0_AD13P_35); also elsewhere on the board
/FPGA_CLK: U30.N11 (IO_L13P_T2_MRCC_14); also elsewhere on the board
/MIX_ENBL: U30.J4 (IO_L19N_T3_VREF_35); also elsewhere on the board
/PA_EN: U30.T2 (IO_L8N_T1_34); also elsewhere on the board
/fpga/ADC_OE1: U30.B2 (IO_L8P_T1_AD14P_35); also elsewhere on the board
/fpga/ADC_OE2: U30.P1 (IO_L4N_T0_34); also elsewhere on the board
/fpga/ADC_SHDN1: U30.B1 (IO_L9N_T1_DQS_AD7N_35); also elsewhere on the board
/fpga/ADC_SHDN2: U30.N2 (IO_L3N_T0_DQS_34); also elsewhere on the board
/fpga/CARD_DETECT: U30.H16 (IO_L22P_T3_A17_15); also elsewhere on the board
/fpga/CLKOUT: U30.D13 (IO_L12P_T1_MRCC_15); also elsewhere on the board
/fpga/D0: U30.L2 (IO_L23N_T3_35); also elsewhere on the board
/fpga/D1: U30.K2 (IO_L24N_T3_35); also elsewhere on the board
/fpga/D2: U30.K1 (IO_L22P_T3_35); also elsewhere on the board
/fpga/D3: U30.J3 (IO_L21P_T3_DQS_35); also elsewhere on the board
/fpga/D4: U30.H1 (IO_L20N_T3_35); also elsewhere on the board
/fpga/D5: U30.H2 (IO_L20P_T3_35); also elsewhere on the board
/fpga/D6: U30.H3 (IO_L21N_T3_DQS_35); also elsewhere on the board
/fpga/D7: U30.G2 (IO_L17P_T2_35); also elsewhere on the board
/fpga/D8: U30.G1 (IO_L17N_T2_35); also elsewhere on the board
/fpga/D9: U30.F2 (IO_L15P_T2_DQS_35); also elsewhere on the board
/fpga/D10: U30.E1 (IO_L15N_T2_DQS_35); also elsewhere on the board
/fpga/D11: U30.E2 (IO_L10P_T1_AD15P_35); also elsewhere on the board
/fpga/FT_D0: U30.F15 (IO_L18P_T2_A24_15); also elsewhere on the board
/fpga/FT_D1: U30.G16 (IO_L22N_T3_A16_15); also elsewhere on the board
/fpga/FT_D2: U30.G15 (IO_L24N_T3_RS0_15); also elsewhere on the board
/fpga/FT_D3: U30.F14 (IO_L21N_T3_DQS_A18_15); also elsewhere on the board
/fpga/FT_D4: U30.E16 (IO_L17P_T2_A26_15); also elsewhere on the board
/fpga/FT_D5: U30.E15 (IO_L18N_T2_A23_15); also elsewhere on the board
/fpga/FT_D6: U30.D16 (IO_L17N_T2_A25_15); also elsewhere on the board
/fpga/FT_D7: U30.D15 (IO_L15N_T2_DQS_ADV_B_15); also elsewhere on the board
/fpga/FT_SUSPEND: U30.C16 (IO_L10P_T1_AD11P_15); also elsewhere on the board
/fpga/FT_TCK: JP4.2 (B); also elsewhere on the board
/fpga/FT_TDI: JP3.2 (B); also elsewhere on the board
/fpga/FT_TDO: JP2.2 (B); also elsewhere on the board
/fpga/FT_TMS: JP1.2 (B); also elsewhere on the board
/fpga/INIT_B: U30.K10 (INIT_B_0); also elsewhere on the board
/fpga/M0: U30.M9 (M0_0); also elsewhere on the board
/fpga/M1: U30.M10 (M1_0); also elsewhere on the board
/fpga/M2: U30.M11 (M2_0); also elsewhere on the board
/fpga/OE#: U30.A12 (IO_L5N_T0_AD9N_15); also elsewhere on the board
/fpga/OFA: U30.C2 (IO_L7N_T1_AD6N_35); also elsewhere on the board
/fpga/OFB: U30.M1 (IO_L2N_T0_34); also elsewhere on the board
/fpga/PIN1: U30.C11 (IO_L11P_T1_SRCC_15); also elsewhere on the board
/fpga/PIN2: U30.B10 (IO_L4P_T0_15); also elsewhere on the board
/fpga/PIN3: U30.A9 (IO_L2N_T0_AD8N_15); also elsewhere on the board
/fpga/PIN4: U30.C12 (IO_L11N_T1_SRCC_15); also elsewhere on the board
/fpga/PIN5: U30.B9 (IO_L3P_T0_DQS_AD1P_15); also elsewhere on the board
/fpga/PIN6: U30.A8 (IO_L2P_T0_AD8P_15); also elsewhere on the board
/fpga/PIN7: U30.B7 (IO_L1P_T0_AD4P_35); also elsewhere on the board
/fpga/PIN8: U30.A5 (IO_L3P_T0_DQS_AD5P_35); also elsewhere on the board
/fpga/PIN9: U30.A4 (IO_L3N_T0_DQS_AD5N_35); also elsewhere on the board
/fpga/PIN10: U30.A7 (IO_L1N_T0_AD4N_35); also elsewhere on the board
/fpga/PIN11: U30.B5 (IO_L2N_T0_AD12N_35); also elsewhere on the board
/fpga/PIN12: U30.A3 (IO_L4N_T0_35); also elsewhere on the board
/fpga/PROG_B: U30.L9 (PROGRAM_B_0); also elsewhere on the board
/fpga/RD#: U30.A15 (IO_L9N_T1_DQS_AD3N_15); also elsewhere on the board
/fpga/RESET: U30.B4 (IO_L4P_T0_35); also elsewhere on the board
/fpga/RXF#: U30.B16 (IO_L10N_T1_AD11N_15); also elsewhere on the board
/fpga/SD_CLK: U30.N14 (IO_L12P_T1_MRCC_14); also elsewhere on the board
/fpga/SD_CMD: U30.P16 (IO_L8N_T1_D12_14); also elsewhere on the board
/fpga/SD_DAT0: U30.N16 (IO_L7N_T1_D10_14); also elsewhere on the board
/fpga/SD_DAT1: U30.M16 (IO_L7P_T1_D09_14); also elsewhere on the board
/fpga/SD_DAT2: U30.R16 (IO_L9N_T1_DQS_D13_14); also elsewhere on the board
/fpga/SD_DAT3: U30.R15 (IO_L9P_T1_DQS_14); also elsewhere on the board
/fpga/SIWUA: U30.A13 (IO_L7P_T1_AD2P_15); also elsewhere on the board
/fpga/SPI_CLK: U30.E8 (CCLK_0), U42.1; also elsewhere on the board
/fpga/SPI_CS: U30.L12 (IO_L6P_T0_FCS_B_14); also elsewhere on the board
/fpga/SPI_MISO: U30.J14 (IO_L1N_T0_D01_DIN_14), U44.1; also elsewhere on the board
/fpga/SPI_MOSI: U30.J13 (IO_L1P_T0_D00_MOSI_14), U43.1; also elsewhere on the board
/fpga/TCK: JP4.1 (A), U4.1, U30.L7 (TCK_0)
/fpga/TDI: JP3.1 (A), U30.N7 (TDI_0), U35.1
/fpga/TDO: JP2.1 (A), U30.N8 (TDO_0), U38.1
/fpga/TMS: JP1.1 (A), U30.M7 (TMS_0), U41.1
/fpga/TXE#: U30.B15 (IO_L9P_T1_DQS_AD3P_15); also elsewhere on the board
/fpga/USER_LED: U30.B12 (IO_L5P_T0_AD9P_15); also elsewhere on the board
/fpga/WR: U30.A14 (IO_L7N_T1_AD2N_15); also elsewhere on the board
GND: C205.2, R70.2, U30.A1 (GND), U30.A11 (GND), U30.B8 (GND), U30.C5 (GND), U30.C15 (GND), U30.D2 (GND), U30.D12 (GND), U30.E9 (GND), U30.F6 (GND), U30.F8 (VCCBATT_0), U30.F10 (GND), U30.F16 (GND), U30.G3 (GND), U30.G7 (GNDADC_0), U30.G9 (GND), U30.G13 (GND), U30.H6 (GND), U30.H7 (VREFN_0), U30.J7 (VN_0), U30.J8 (VREFP_0), U30.J9 (GND), U30.J11 (GND), U30.K4 (GND), U30.K6 (GND), U30.K7 (DXN_0), U30.K8 (DXP_0), U30.K14 (GND), U30.L1 (GND), U30.L11 (GND), U30.M8 (GND), U30.N5 (GND), U30.N15 (GND), U30.P2 (GND), U30.P12 (GND), U30.R9 (GND), U30.T6 (GND), U30.T16 (GND); also elsewhere on the board
unnamed: D2.2 (A), R111.2
unnamed: D2.1 (K), U30.H10 (DONE_0)
unnamed: R69.2, R70.1, U30.L15 (IO_L3P_T0_DQS_PUDC_B_14)
unnamed: R130.1, U30.R1 (IO_L7N_T1_34)

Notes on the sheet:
Internal reference

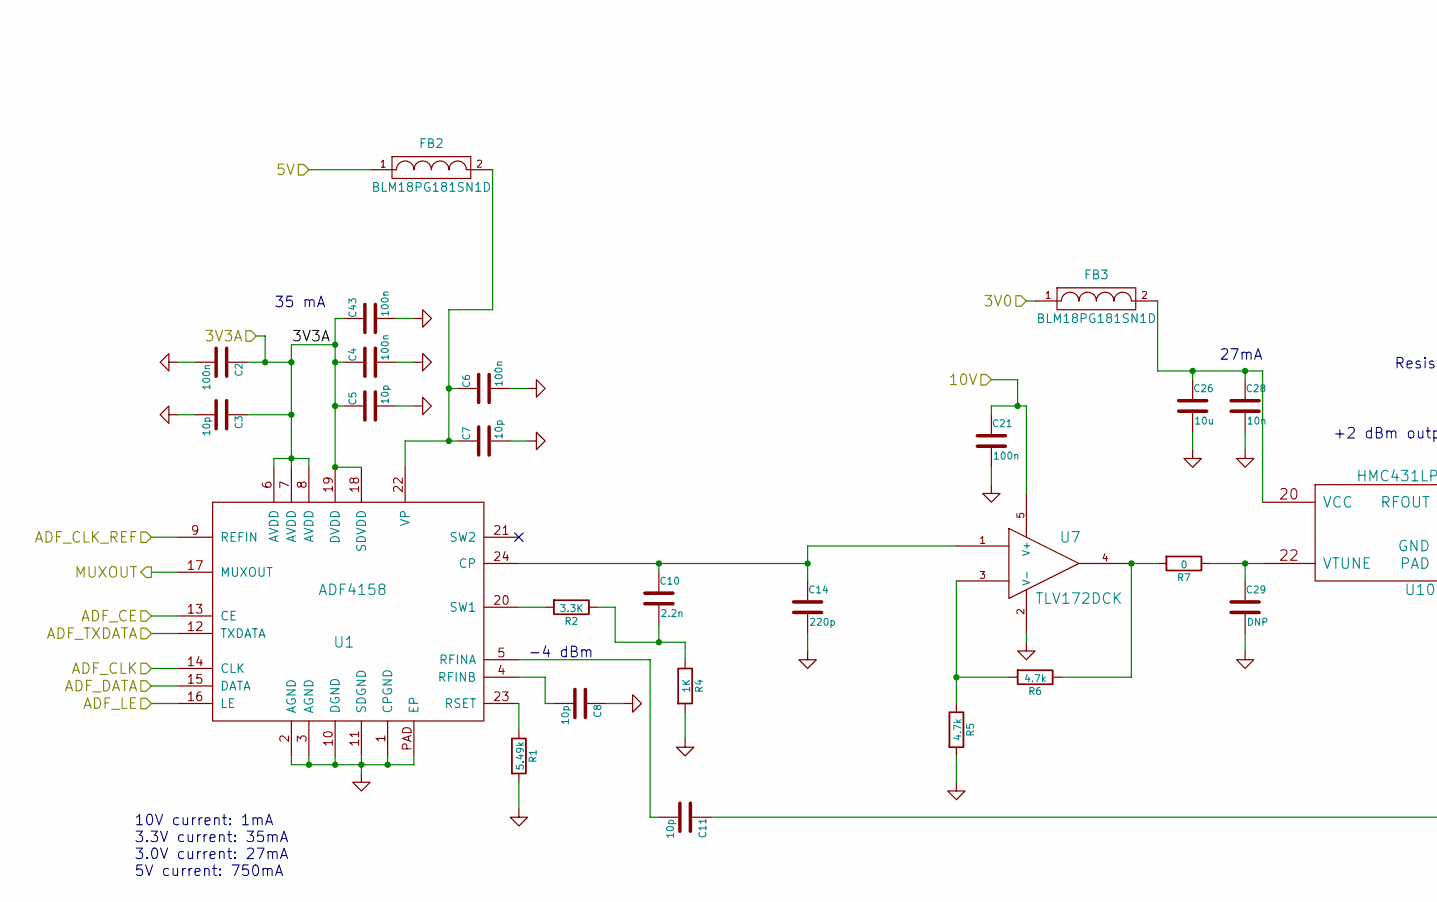
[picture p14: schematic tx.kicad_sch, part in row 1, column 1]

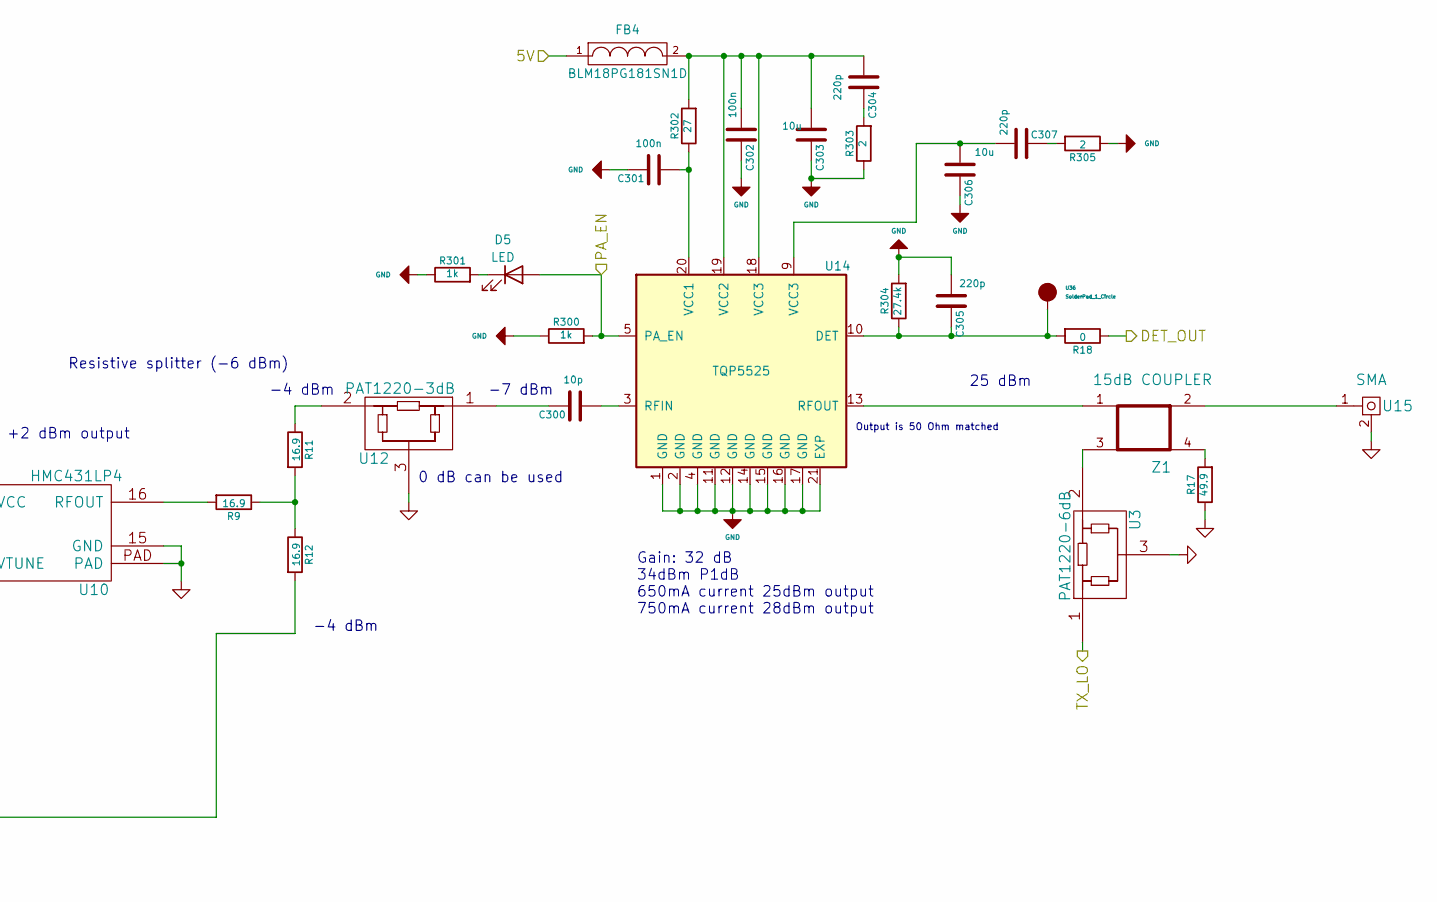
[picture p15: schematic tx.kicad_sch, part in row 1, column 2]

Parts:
C2, C4, C6, C21, C43, C301, C302: 100n; SMD_0402
C3, C5, C7, C8, C11, C300: 10p; SMD_0402
C10: 2.2n; SMD_0402
C14, C304, C305, C307: 220p; SMD_0402
C26, C303, C306: 10u; SMD_0805
C28: 10n; SMD_0402
C29: DNP; SMD_0402
D5: LED; Diode_0603
FB2, FB3, FB4: BLM18PG181SN1D; SMD_0603
R1: 5.49k; SMD_0402
R2: 3.3K; SMD_0402
R4: 1K; SMD_0402
R5, R6: 4.7k; SMD_0402
R7, R18: 0; SMD_0402
R9, R11, R12: 16.9; SMD_0402
R17: 49.9; SMD_0402
R300, R301: 1k; SMD_0402
R302: 27; SMD_0402
R303, R305: 2; SMD_0603
R304: 27.4k; SMD_0402
U1: ADF4158; VFQFN-24
U3: PAT1220-6dB; PAT1220
U7: TLV172DCK; SOT-353_SC-70-5
U10: HMC431LP4; VQFN-24
U12: PAT1220-3dB; PAT1220
U14: TQP5525; QFN-20-1EP_4x4mm_P0.5mm_EP2.5x2.5mm_ThermalVias
U15: SMA; CONSMA003.062
U36: SolderPad_1_Circle; SolderPad_1_1.5mm_SMD_Circle
Z1: 15dB COUPLER; Directional_Coupler_15dB_0.169mm_v2

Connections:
/3V0: FB3.1; also elsewhere on the board
/3V3A: C2.1, C3.1, C4.1, C5.1, C43.1, U1.6 (AVDD), U1.7 (AVDD), U1.8 (AVDD), U1.18 (SDVDD), U1.19 (DVDD); also elsewhere on the board
/5V: FB2.1, FB4.1; also elsewhere on the board
/10V: C21.1, U7.5 (V+); also elsewhere on the board
/ADF_CE: U1.13 (CE); also elsewhere on the board
/ADF_CLK: U1.14 (CLK); also elsewhere on the board
/ADF_CLK_REF: U1.9 (REFIN); also elsewhere on the board
/ADF_DATA: U1.15 (DATA); also elsewhere on the board
/ADF_LE: U1.16 (LE); also elsewhere on the board
/ADF_MUXOUT: U1.17 (MUXOUT); also elsewhere on the board
/ADF_TXDATA: U1.12 (TXDATA); also elsewhere on the board
/DET_OUT: R18.1; also elsewhere on the board
/LO: U3.1; also elsewhere on the board
/PA_EN: D5.2 (A), R300.2, U14.5 (PA_EN); also elsewhere on the board
GND: C2.2, C3.2, C4.2, C5.2, C6.2, C7.2, C8.1, C14.2, C21.2, C26.2, C28.2, C29.2, C43.2, C301.1, C302.1, C303.1, C305.2, C306.1, R1.2, R4.2, R5.2, R17.1, R300.1, R301.1, R303.1, R304.2, R305.1, U1.1 (CPGND), U1.2 (AGND), U1.3 (AGND), U1.10 (DGND), U1.11 (SDGND), U1.PAD (EP), U3.3, U7.2 (V-), U10.15 (GND), U10.PAD, U12.3, U14.1 (GND), U14.2 (GND), U14.4 (GND), U14.11 (GND), U14.12 (GND), U14.14 (GND), U14.15 (GND), U14.16 (GND), U14.17 (GND), U14.21 (EXP), U15.2; also elsewhere on the board
unnamed: C10.2, R2.1, R4.1
unnamed: C11.1, R12.2
unnamed: C300.1, U12.1
unnamed: C304.1, R303.2
unnamed: C306.2, C307.2, U14.9 (VCC3)
unnamed: C307.1, R305.2
unnamed: D5.1 (K), R301.2
unnamed: R5.1, R6.2, U7.3
unnamed: R6.1, R7.2, U7.4
unnamed: R11.1, U12.2
unnamed: R9.1, R11.2, R12.1
unnamed: R17.2, Z1.4
unnamed: C10.1, C14.1, U1.24 (CP), U7.1
unnamed: C11.2, U1.5 (RFINA)
unnamed: C8.2, U1.4 (RFINB)
unnamed: R1.1, U1.23 (RSET)
unnamed: R2.2, U1.20 (SW1)
unnamed: C6.1, C7.1, FB2.2, U1.22 (VP)
unnamed: U3.2, Z1.3
unnamed: R9.2, U10.16 (RFOUT)
unnamed: C26.1, C28.1, FB3.2, U10.20 (VCC)
unnamed: C29.1, R7.1, U10.22 (VTUNE)
unnamed: C305.1, R18.2, R304.1, U14.10 (DET), U36.1
unnamed: C300.2, U14.3 (RFIN)
unnamed: U14.13 (RFOUT), Z1.1
unnamed: C301.2, R302.1, U14.20 (VCC1)
unnamed: C302.2, C303.2, C304.2, FB4.2, R302.2, U14.18 (VCC3), U14.19 (VCC2)
unnamed: U15.1, Z1.2

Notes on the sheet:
Resistive splitter (-6 dBm)
-4 dBm
10V current: 1mA 3.3V current: 35mA 3.0V current: 27mA 5V current: 750mA
+2 dBm output
35 mA
-7 dBm
27mA
Output is 50 Ohm matched
Gain: 32 dB 34dBm P1dB 650mA current 25dBm output 750mA current 28dBm output
0 dB can be used
25 dBm

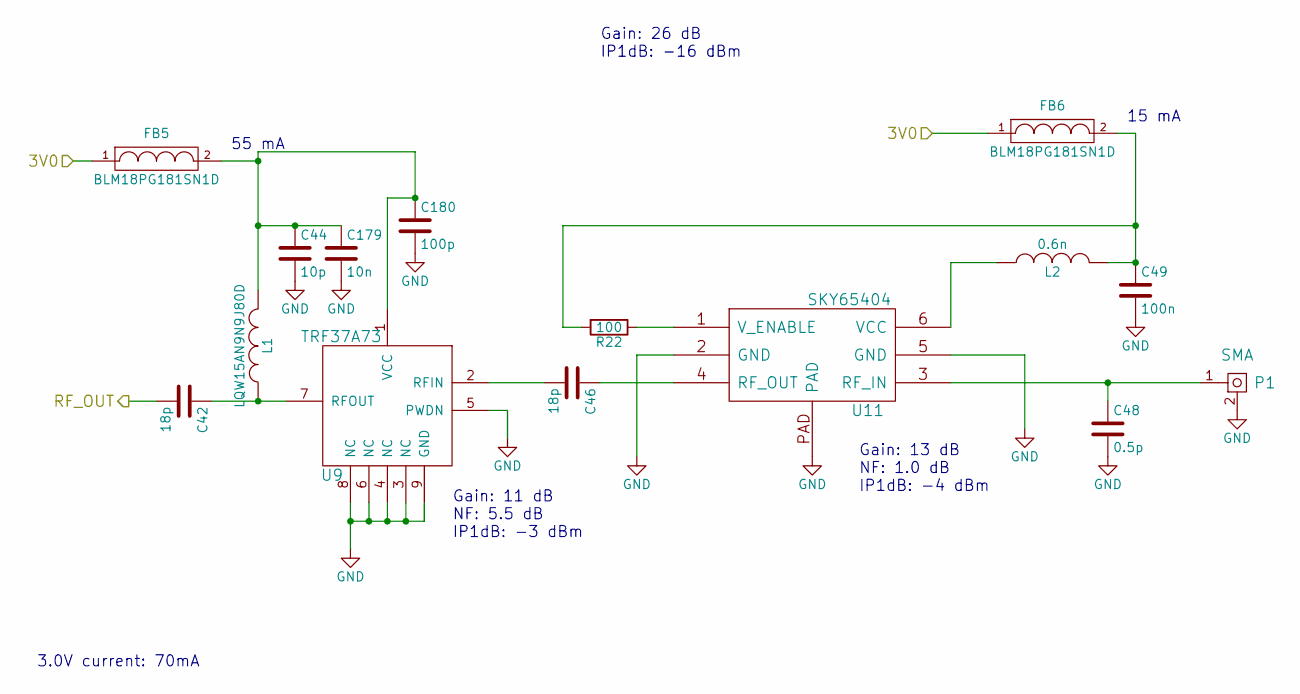
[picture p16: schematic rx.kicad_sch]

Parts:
C42, C46: 18p; SMD_0402
C44: 10p; SMD_0402
C48: 0.5p; SMD_0402
C49: 100n; SMD_0402
C179: 10n; SMD_0402
C180: 100p; SMD_0402
FB5, FB6: BLM18PG181SN1D; SMD_0603
L1: LQW15AN9N9J80D; SMD_0402
L2: 0.6n; SMD_0402
P1: SMA; CONSMA003.062
R22: 100; SMD_0402
U9: TRF37A73; DFN-8-1EP_2x2mm_Pitch0.5mm
U11: SKY65404; XFDFN-6

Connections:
/3V0: FB5.1, FB6.1; also elsewhere on the board
/RF1: C42.2; also elsewhere on the board
GND: C44.2, C48.2, C49.2, C179.2, C180.2, P1.2, U9.3 (NC), U9.4 (NC), U9.5 (PWDN), U9.6 (NC), U9.8 (NC), U9.9 (GND), U11.2 (GND), U11.5 (GND), U11.PAD; also elsewhere on the board
unnamed: C49.1, FB6.2, L2.2, R22.2
unnamed: C46.2, U9.2 (RFIN)
unnamed: C42.1, L1.1, U9.7 (RFOUT)
unnamed: C44.1, C179.1, C180.1, FB5.2, L1.2, U9.1 (VCC)
unnamed: C48.1, P1.1, U11.3 (RF_IN)
unnamed: C46.1, U11.4 (RF_OUT)
unnamed: L2.1, U11.6 (VCC)
unnamed: R22.1, U11.1 (V_ENABLE)

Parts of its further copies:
C52, C55: 18p; SMD_0402
C53: 10p; SMD_0402
C57: 0.5p; SMD_0402
C58: 100n; SMD_0402
C206: 10n; SMD_0402
C213: 100p; SMD_0402
FB7, FB8: BLM18PG181SN1D; SMD_0603
L3: LQW15AN9N9J80D; SMD_0402
L4: 0.6n; SMD_0402
P2: SMA; CONSMA003.062
R23: 100; SMD_0402
U13: TRF37A73; DFN-8-1EP_2x2mm_Pitch0.5mm
U16: SKY65404; XFDFN-6

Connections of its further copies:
/3V0: FB7.1, FB8.1; also elsewhere on the board
/RF2: C52.2; also elsewhere on the board
GND: C53.2, C57.2, C58.2, C206.2, C213.2, P2.2, U13.3 (NC), U13.4 (NC), U13.5 (PWDN), U13.6 (NC), U13.8 (NC), U13.9 (GND), U16.2 (GND), U16.5 (GND), U16.PAD; also elsewhere on the board
unnamed: C58.1, FB8.2, L4.2, R23.2
unnamed: C55.2, U13.2 (RFIN)
unnamed: C52.1, L3.1, U13.7 (RFOUT)
unnamed: C53.1, C206.1, C213.1, FB7.2, L3.2, U13.1 (VCC)
unnamed: C57.1, P2.1, U16.3 (RF_IN)
unnamed: C55.1, U16.4 (RF_OUT)
unnamed: L4.1, U16.6 (VCC)
unnamed: R23.1, U16.1 (V_ENABLE)

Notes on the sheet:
Gain: 11 dB NF: 5.5 dB IP1dB: -3 dBm
15 mA
Gain: 13 dB NF: 1.0 dB IP1dB: -4 dBm
3.0V current: 70mA
55 mA
Gain: 26 dB IP1dB: -16 dBm

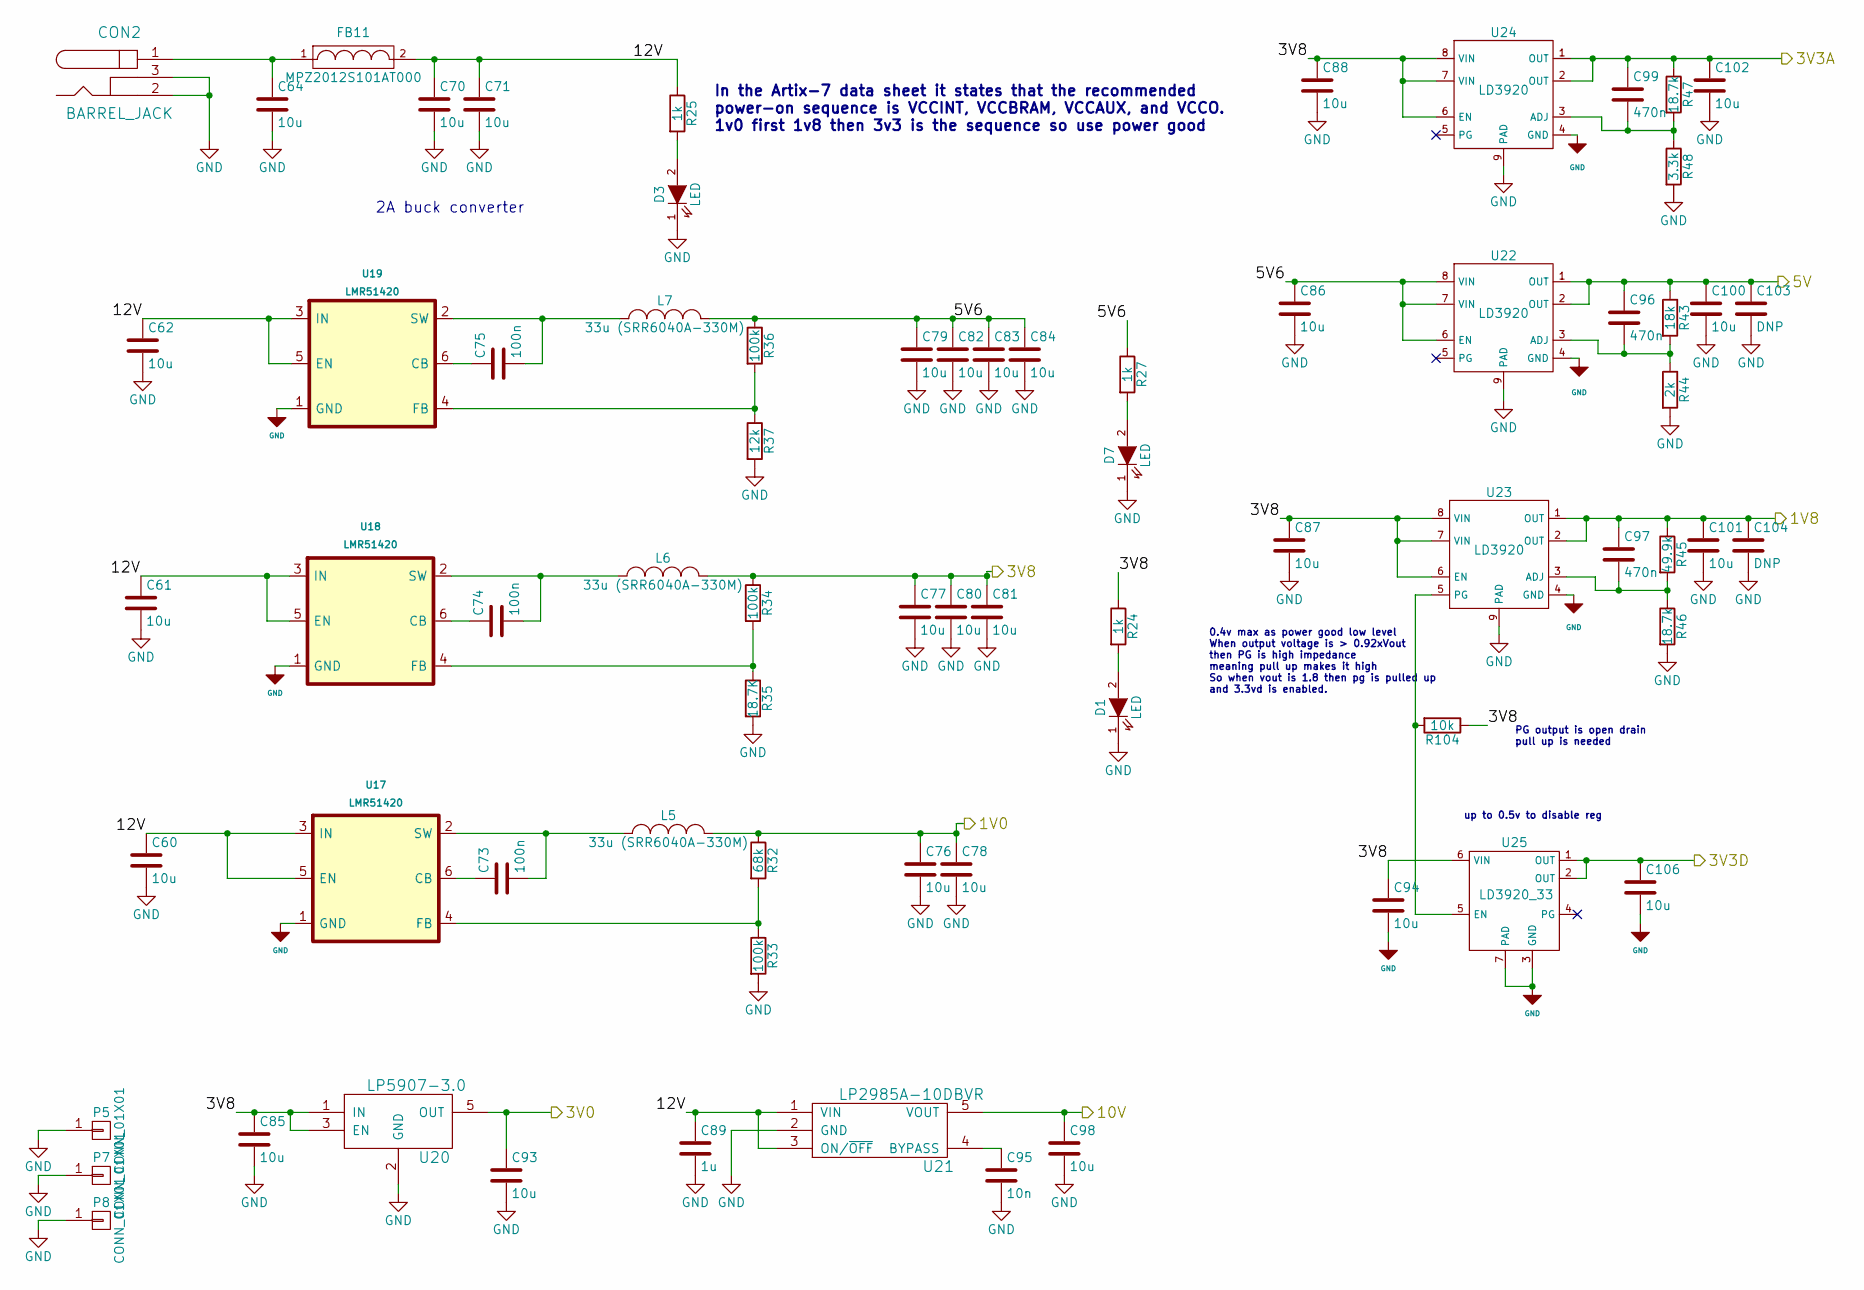
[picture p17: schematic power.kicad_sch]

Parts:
C60, C61, C62, C64, C70, C71, C76, C77, C78, C79, C80, C81, C82, C83, C84, C85, C86, C87, C88, C93, C94, C98, C100, C101, C102, C106: 10u; SMD_0805
C73, C74, C75: 100n; SMD_0402
C89: 1u; SMD_0603
C95: 10n; SMD_0402
C96, C97, C99: 470n; SMD_0402
C103, C104: DNP; SMD_0805
CON2: BARREL_JACK; BarrelJack
D1, D3, D7: LED; Diode_0603
FB11: MPZ2012S101AT000; SMD_0805
L5, L6, L7: 33u (SRR6040A-330M); SRR6040A
P5, P7, P8: CONN_01X01; MountingHole_3.2mm_M3_Pad_Via_mod
R24, R25, R27: 1k; SMD_0402
R32: 68k; SMD_0402
R33, R34, R36: 100k; SMD_0402
R35: 18.7K; SMD_0402
R37: 12k; SMD_0402
R43: 18k; SMD_0402
R44: 2k; SMD_0402
R45: 49.9k; SMD_0402
R46, R47: 18.7k; SMD_0402
R48: 3.3k; SMD_0402
R104: 10k; SMD_0402
U17, U18, U19: LMR51420; SOT23_6
U20: LP5907-3.0; SOT-23-5
U21: LP2985A-10DBVR; SOT-23-5
U22, U23, U24: LD3920; DFN-8-1EP_4x4mm_P0.8mm_EP2.3x3.24mm
U25: LD3920_33; DFN-6-1EP_3x3mm_P0.95mm_EP1.7x2.6mm

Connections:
/1V0: C76.1, C78.1, L5.2, R32.1; also elsewhere on the board
/1V8: C97.1, C101.1, C104.1, R45.1, U23.1 (OUT), U23.2 (OUT); also elsewhere on the board
/3V0: C93.1, U20.5 (OUT); also elsewhere on the board
/3V3A: C99.1, C102.1, R47.1, U24.1 (OUT), U24.2 (OUT); also elsewhere on the board
/3V3D: C106.1, U25.1 (OUT), U25.2 (OUT); also elsewhere on the board
/3V8: C77.1, C80.1, C81.1, C85.1, C87.1, C88.1, C94.1, L6.2, R24.1, R34.1, R104.1, U20.1 (IN), U20.3 (EN), U23.6 (EN), U23.7 (VIN), U23.8 (VIN), U24.6 (EN), U24.7 (VIN), U24.8 (VIN), U25.6 (VIN); also elsewhere on the board
/5V: C96.1, C100.1, C103.1, R43.1, U22.1 (OUT), U22.2 (OUT); also elsewhere on the board
/10V: C98.1, U21.5 (VOUT); also elsewhere on the board
/power/5V6: C79.1, C82.1, C83.1, C84.1, C86.1, L7.2, R27.1, R36.1, U22.6 (EN), U22.7 (VIN), U22.8 (VIN)
/power/12V: C60.1, C61.1, C62.1, C70.1, C71.1, C89.1, FB11.2, R25.1, U17.3 (IN), U17.5 (EN), U18.3 (IN), U18.5 (EN), U19.3 (IN), U19.5 (EN), U21.1 (VIN), U21.3 (ON/~OFF)
GND: C60.2, C61.2, C62.2, C64.2, C70.2, C71.2, C76.2, C77.2, C78.2, C79.2, C80.2, C81.2, C82.2, C83.2, C84.2, C85.2, C86.2, C87.2, C88.2, C89.2, C93.2, C94.2, C95.2, C98.2, C100.2, C101.2, C102.2, C103.2, C104.2, C106.2, CON2.2, CON2.3, D1.1 (K), D3.1 (K), D7.1 (K), P5.1, P7.1, P8.1, R33.2, R35.2, R37.2, R44.2, R46.2, R48.2, U17.1 (GND), U18.1 (GND), U19.1 (GND), U20.2 (GND), U21.2 (GND), U22.4 (GND), U22.9 (PAD), U23.4 (GND), U23.9 (PAD), U24.4 (GND), U24.9 (PAD), U25.3 (GND), U25.7 (PAD); also elsewhere on the board
unnamed: C64.1, CON2.1, FB11.1
unnamed: D1.2 (A), R24.2
unnamed: D3.2 (A), R25.2
unnamed: D7.2 (A), R27.2
unnamed: C73.1, U17.6 (CB)
unnamed: R32.2, R33.1, U17.4 (FB)
unnamed: C73.2, L5.1, U17.2 (SW)
unnamed: C74.1, U18.6 (CB)
unnamed: R34.2, R35.1, U18.4 (FB)
unnamed: C74.2, L6.1, U18.2 (SW)
unnamed: C75.1, U19.6 (CB)
unnamed: R36.2, R37.1, U19.4 (FB)
unnamed: C75.2, L7.1, U19.2 (SW)
unnamed: C95.1, U21.4 (BYPASS)
unnamed: C96.2, R43.2, R44.1, U22.3 (ADJ)
unnamed: C97.2, R45.2, R46.1, U23.3 (ADJ)
unnamed: R104.2, U23.5 (PG), U25.5 (EN)
unnamed: C99.2, R47.2, R48.1, U24.3 (ADJ)

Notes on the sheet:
up to 0.5v to disable reg
0.4v max as power good low level When output voltage is > 0.92xVout then PG is high impedance meaning pull up makes it high So when vout is 1.8 then pg is pulled up and 3.3vd is enabled.
PG output is open drain pull up is needed
In the Artix-7 data sheet it states that the recommended power-on sequence is VCCINT, VCCBRAM, VCCAUX, and VCCO. 1v0 first 1v8 then 3v3 is the sequence so use power good
2A buck converter

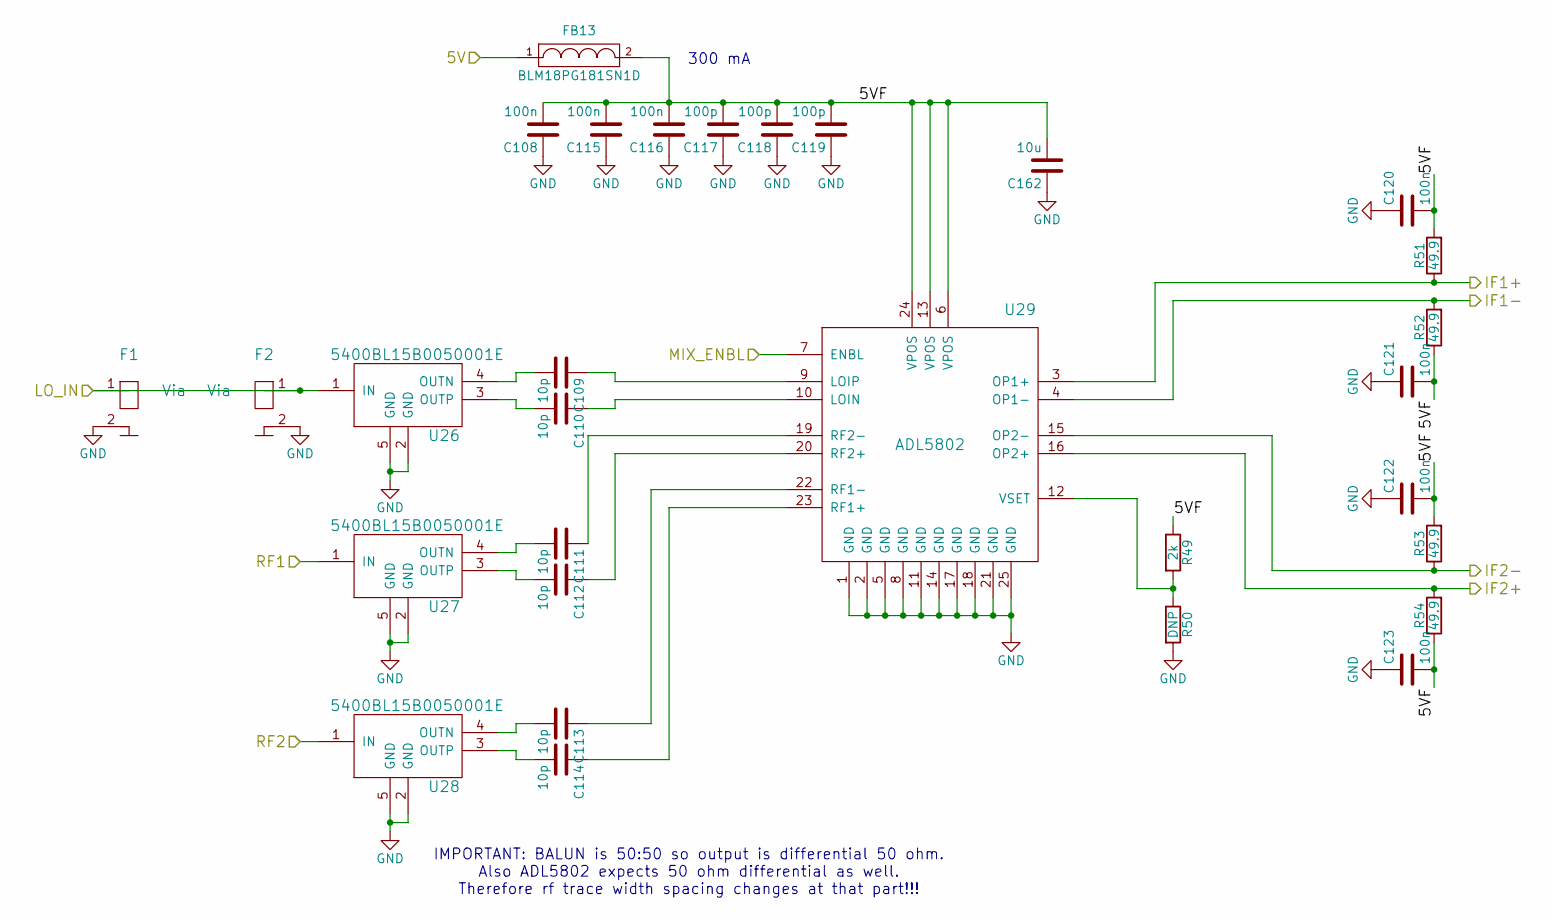
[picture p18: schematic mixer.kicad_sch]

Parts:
C108, C115, C116, C120, C121, C122, C123: 100n; SMD_0402
C109, C110, C111, C112, C113, C114: 10p; SMD_0402
C117, C118, C119: 100p; SMD_0402
C162: 10u; SMD_0805
F1, F2: Via; RF_via
FB13: BLM18PG181SN1D; SMD_0603
R49: 2k; SMD_0402
R50: DNP; SMD_0402
R51, R52, R53, R54: 49.9; SMD_0402
U26, U27, U28: 5400BL15B0050001E; 5400BL15B050E
U29: ADL5802; QFN-24-1EP_4x4mm_Pitch0.5mm

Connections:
/5V: FB13.1; also elsewhere on the board
/LO: F1.1, F2.1, U26.1 (IN); also elsewhere on the board
/MIX_ENBL: U29.7 (ENBL); also elsewhere on the board
/RF1: U27.1 (IN); also elsewhere on the board
/RF2: U28.1 (IN); also elsewhere on the board
/mixer/5VF: C108.2, C115.2, C116.2, C117.2, C118.2, C119.2, C120.2, C121.2, C122.2, C123.2, C162.2, FB13.2, R49.1, R51.2, R52.1, R53.2, R54.1, U29.6 (VPOS), U29.13 (VPOS), U29.24 (VPOS)
/mixer/IF1+: R51.1, U29.3 (OP1+); also elsewhere on the board
/mixer/IF1-: R52.2, U29.4 (OP1-); also elsewhere on the board
/mixer/IF2+: R54.2, U29.16 (OP2+); also elsewhere on the board
/mixer/IF2-: R53.1, U29.15 (OP2-); also elsewhere on the board
GND: C108.1, C115.1, C116.1, C117.1, C118.1, C119.1, C120.1, C121.1, C122.1, C123.1, C162.1, F1.2, F2.2, R50.2, U26.2 (GND), U26.5 (GND), U27.2 (GND), U27.5 (GND), U28.2 (GND), U28.5 (GND), U29.1 (GND), U29.2 (GND), U29.5 (GND), U29.8 (GND), U29.11 (GND), U29.14 (GND), U29.17 (GND), U29.18 (GND), U29.21 (GND), U29.25 (GND); also elsewhere on the board
unnamed: C109.2, U26.4 (OUTN)
unnamed: C110.2, U26.3 (OUTP)
unnamed: C111.2, U27.4 (OUTN)
unnamed: C112.2, U27.3 (OUTP)
unnamed: C113.2, U28.4 (OUTN)
unnamed: C114.2, U28.3 (OUTP)
unnamed: C110.1, U29.10 (LOIN)
unnamed: C109.1, U29.9 (LOIP)
unnamed: C114.1, U29.23 (RF1+)
unnamed: C113.1, U29.22 (RF1-)
unnamed: C112.1, U29.20 (RF2+)
unnamed: C111.1, U29.19 (RF2-)
unnamed: R49.2, R50.1, U29.12 (VSET)

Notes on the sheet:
300 mA
IMPORTANT: BALUN is 50:50 so output is differential 50 ohm. Also ADL5802 expects 50 ohm differential as well. Therefore rf trace width spacing changes at that part!!!

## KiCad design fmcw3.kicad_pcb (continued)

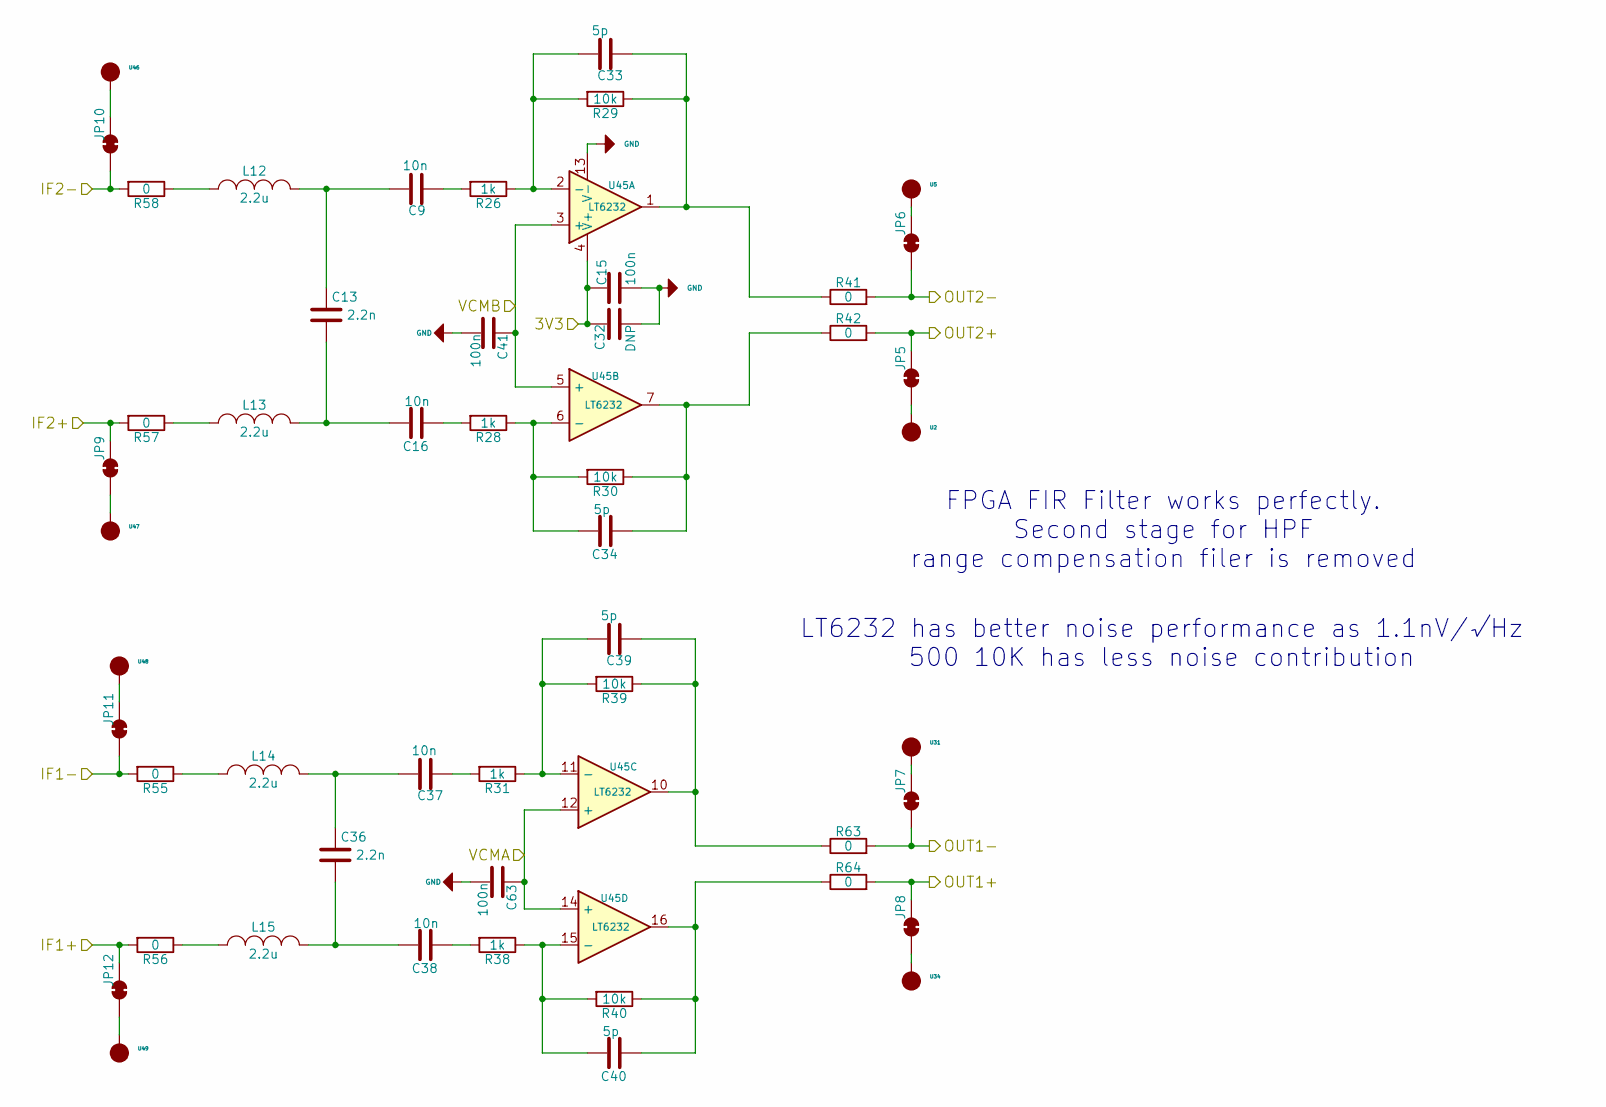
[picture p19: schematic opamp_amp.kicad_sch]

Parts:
C9, C16, C37, C38: 10n; SMD_0402
C13, C36: 2.2n; SMD_0402
C15, C41, C63: 100n; SMD_0402
C32: DNP; SMD_0805
C33, C34, C39, C40: 5p; SMD_0402
JP5, JP6, JP7, JP8, JP9, JP10, JP11, JP12: SolderJumper_2_Bridged; SolderPad_2_Bridge
L12, L13, L14, L15: 2.2u; SMD_0805
R26, R28, R31, R38: 1k; SMD_0402
R29, R30, R39, R40: 10k; SMD_0402
R41, R42, R55, R56, R57, R58, R63, R64: 0; SMD_0402
U2, U5, U31, U34, U46, U47, U48, U49: SolderPad_1_Circle; SolderPad_1_1.0mm_SMD_Circle
U45: LT6232; SSOP16_3.9x4.9mm_P0.635mm

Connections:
/3V3A: C15.1, C32.1, U45.4 (V+); also elsewhere on the board
/ADC1+: JP8.2 (B), R64.2; also elsewhere on the board
/ADC1-: JP7.1 (A), R63.2; also elsewhere on the board
/ADC2+: JP5.2 (B), R42.2; also elsewhere on the board
/ADC2-: JP6.1 (A), R41.2; also elsewhere on the board
/ADC_VCMA: C63.1, U45.12 (+), U45.14 (+); also elsewhere on the board
/ADC_VCMB: C41.1, U45.3 (+), U45.5 (+); also elsewhere on the board
/mixer/IF1+: JP12.2 (B), R56.2; also elsewhere on the board
/mixer/IF1-: JP11.1 (A), R55.2; also elsewhere on the board
/mixer/IF2+: JP9.2 (B), R57.2; also elsewhere on the board
/mixer/IF2-: JP10.1 (A), R58.2; also elsewhere on the board
GND: C15.2, C32.2, C41.2, C63.2, U45.13 (V-); also elsewhere on the board
unnamed: C9.1, R26.2
unnamed: C9.2, C13.1, L12.2
unnamed: C13.2, C16.2, L13.2
unnamed: C16.1, R28.2
unnamed: C33.1, R29.1, R41.1, U45.1
unnamed: C34.1, R30.1, R42.1, U45.7
unnamed: C36.1, C37.2, L14.2
unnamed: C36.2, C38.2, L15.2
unnamed: C37.1, R31.2
unnamed: C38.1, R38.2
unnamed: C39.1, R39.1, R63.1, U45.10
unnamed: C40.1, R40.1, R64.1, U45.16
unnamed: JP5.1 (A), U2.1
unnamed: JP6.2 (B), U5.1
unnamed: JP7.2 (B), U31.1
unnamed: JP8.1 (A), U34.1
unnamed: JP9.1 (A), U47.1
unnamed: JP10.2 (B), U46.1
unnamed: JP11.2 (B), U48.1
unnamed: JP12.1 (A), U49.1
unnamed: L12.1, R58.1
unnamed: L13.1, R57.1
unnamed: L14.1, R55.1
unnamed: L15.1, R56.1
unnamed: C33.2, R26.1, R29.2, U45.2 (-)
unnamed: C34.2, R28.1, R30.2, U45.6 (-)
unnamed: C39.2, R31.1, R39.2, U45.11 (-)
unnamed: C40.2, R38.1, R40.2, U45.15 (-)

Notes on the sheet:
LT6232 has better noise performance as 1.1nV/√Hz 500 10K has less noise contribution
FPGA FIR Filter works perfectly. Second stage for HPF range compensation filer is removed

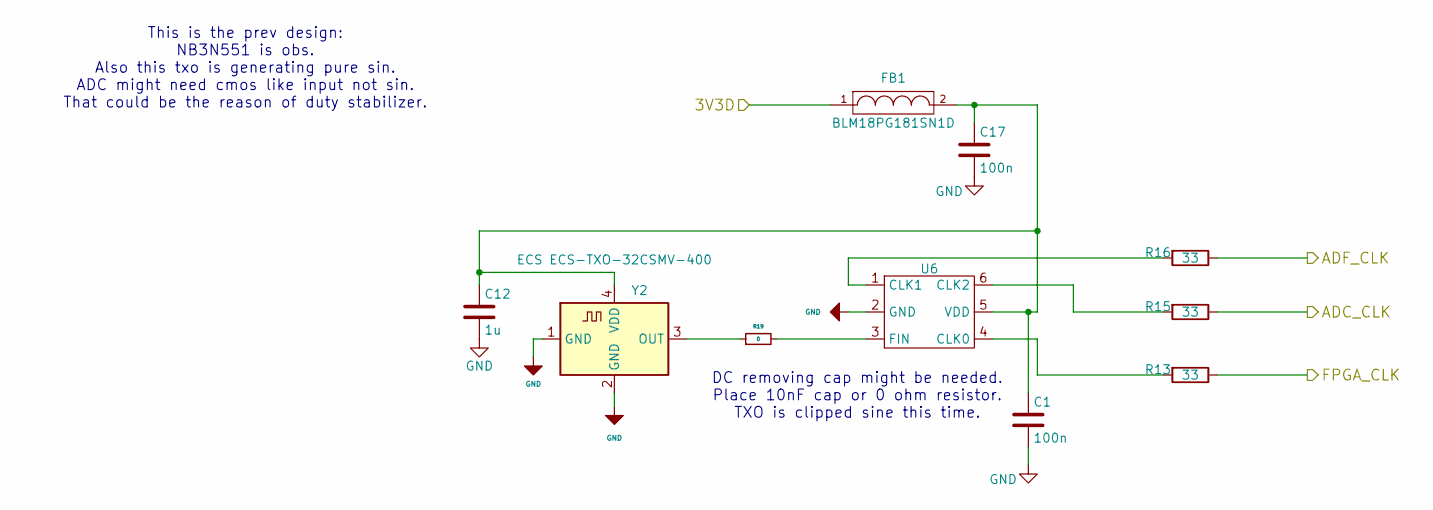
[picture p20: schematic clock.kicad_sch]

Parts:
C1, C17: 100n; SMD_0402
C12: 1u; SMD_0603
FB1: BLM18PG181SN1D; SMD_0603
R13, R15, R16: 33; SMD_0402
R19: 0; SMD_0402
U6: PL133-37; SOT23_6
Y2: ECS ECS-TXO-32CSMV-400; Oscillator_SMD_ECS_2520MV-xxx-xx-4Pin_2.5x2.0mm

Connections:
/3V3D: FB1.1; also elsewhere on the board
/ADC_CLK: R15.1; also elsewhere on the board
/ADF_CLK_REF: R16.1; also elsewhere on the board
/FPGA_CLK: R13.1; also elsewhere on the board
GND: C1.2, C12.2, C17.2, U6.2 (GND), Y2.1 (GND), Y2.2 (GND); also elsewhere on the board
unnamed: R13.2, U6.4 (CLK0)
unnamed: R16.2, U6.1 (CLK1)
unnamed: R15.2, U6.6 (CLK2)
unnamed: R19.2, U6.3 (FIN)
unnamed: C1.1, C12.1, C17.1, FB1.2, U6.5 (VDD), Y2.4 (VDD)
unnamed: R19.1, Y2.3 (OUT)

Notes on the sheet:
DC removing cap might be needed. Place 10nF cap or 0 ohm resistor. TXO is clipped sine this time.
This is the prev design: NB3N551 is obs. Also this txo is generating pure sin. ADC might need cmos like input not sin. That could be the reason of duty stabilizer.

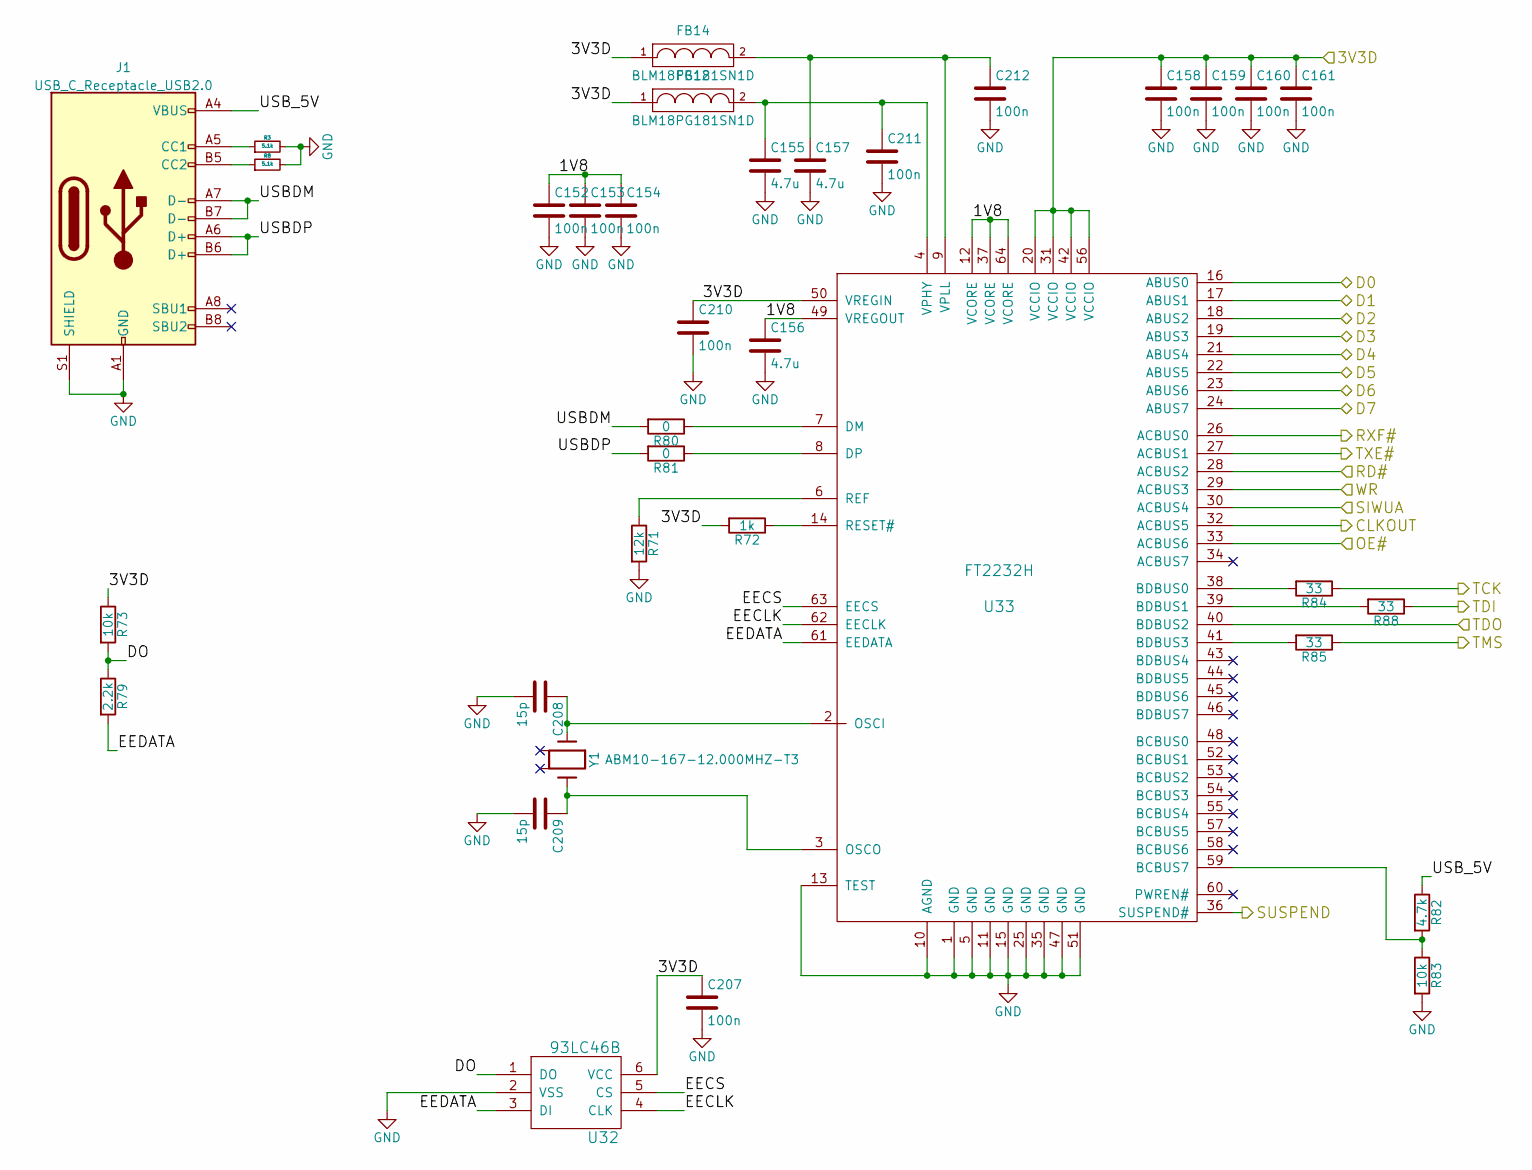
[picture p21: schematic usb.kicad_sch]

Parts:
C152, C153, C154, C158, C159, C160, C161, C207, C210, C211, C212: 100n; SMD_0402
C155, C156, C157: 4.7u; SMD_0603
C208, C209: 15p; SMD_0402
FB12, FB14: BLM18PG181SN1D; SMD_0603
J1: USB_C_Receptacle_USB2.0; USB_C_Receptacle_GCT_USB4105-xx-A_16P_TopMnt_Horizontal
R3, R8: 5.1k; SMD_0402
R71: 12k; SMD_0402
R72: 1k; SMD_0402
R73, R83: 10k; SMD_0402
R79: 2.2k; SMD_0402
R80, R81: 0; SMD_0402
R82: 4.7k; SMD_0402
R84, R85, R88: 33; SMD_0402
U32: 93LC46B; SOT-23-6
U33: FT2232H; LQFP-64_10x10mm_Pitch0.5mm
Y1: ABM10-167-12.000MHZ-T3; ABM10

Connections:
/3V3D: C158.1, C159.1, C160.1, C161.1, C207.1, C210.1, FB12.1, FB14.1, R72.2, R73.1, U32.6 (VCC), U33.20 (VCCIO), U33.31 (VCCIO), U33.42 (VCCIO), U33.50 (VREGIN), U33.56 (VCCIO); also elsewhere on the board
/fpga/CLKOUT: U33.32 (ACBUS5); also elsewhere on the board
/fpga/FT_D0: U33.16 (ABUS0); also elsewhere on the board
/fpga/FT_D1: U33.17 (ABUS1); also elsewhere on the board
/fpga/FT_D2: U33.18 (ABUS2); also elsewhere on the board
/fpga/FT_D3: U33.19 (ABUS3); also elsewhere on the board
/fpga/FT_D4: U33.21 (ABUS4); also elsewhere on the board
/fpga/FT_D5: U33.22 (ABUS5); also elsewhere on the board
/fpga/FT_D6: U33.23 (ABUS6); also elsewhere on the board
/fpga/FT_D7: U33.24 (ABUS7); also elsewhere on the board
/fpga/FT_SUSPEND: U33.36 (SUSPEND#); also elsewhere on the board
/fpga/FT_TCK: R84.1; also elsewhere on the board
/fpga/FT_TDI: R88.1; also elsewhere on the board
/fpga/FT_TDO: U33.40 (BDBUS2); also elsewhere on the board
/fpga/FT_TMS: R85.1; also elsewhere on the board
/fpga/OE#: U33.33 (ACBUS6); also elsewhere on the board
/fpga/RD#: U33.28 (ACBUS2); also elsewhere on the board
/fpga/RXF#: U33.26 (ACBUS0); also elsewhere on the board
/fpga/SIWUA: U33.30 (ACBUS4); also elsewhere on the board
/fpga/TXE#: U33.27 (ACBUS1); also elsewhere on the board
/fpga/WR: U33.29 (ACBUS3); also elsewhere on the board
/fpga/usb/1V8: C152.1, C153.1, C154.1, C156.1, U33.12 (VCORE), U33.37 (VCORE), U33.49 (VREGOUT), U33.64 (VCORE)
/fpga/usb/DO: R73.2, R79.1, U32.1 (DO)
/fpga/usb/EECLK: U32.4 (CLK), U33.62 (EECLK)
/fpga/usb/EECS: U32.5 (CS), U33.63 (EECS)
/fpga/usb/EEDATA: R79.2, U32.3 (DI), U33.61 (EEDATA)
/fpga/usb/USBDM: J1.A7 (D-), J1.B7 (D-), R80.2
/fpga/usb/USBDP: J1.A6 (D+), J1.B6 (D+), R81.2
/fpga/usb/USB_5V: J1.A4 (VBUS), J1.A9 (VBUS), J1.B4 (VBUS), J1.B9 (VBUS), R82.1
GND: C152.2, C153.2, C154.2, C155.2, C156.2, C157.2, C158.2, C159.2, C160.2, C161.2, C207.2, C208.2, C209.2, C210.2, C211.2, C212.2, J1.A1 (GND), J1.A12 (GND), J1.B1 (GND), J1.B12 (GND), J1.S1 (SHIELD), R3.2, R8.2, R71.2, R83.2, U32.2 (VSS), U33.1 (GND), U33.5 (GND), U33.10 (AGND), U33.11 (GND), U33.13 (TEST), U33.15 (GND), U33.25 (GND), U33.35 (GND), U33.47 (GND), U33.51 (GND); also elsewhere on the board
unnamed: J1.A5 (CC1), R3.1
unnamed: J1.B5 (CC2), R8.1
unnamed: R82.2, R83.1, U33.59 (BCBUS7)
unnamed: R84.2, U33.38 (BDBUS0)
unnamed: R88.2, U33.39 (BDBUS1)
unnamed: R85.2, U33.41 (BDBUS3)
unnamed: R80.1, U33.7 (DM)
unnamed: R81.1, U33.8 (DP)
unnamed: C208.1, U33.2 (OSCI), Y1.1
unnamed: C209.1, U33.3 (OSCO), Y1.3
unnamed: R71.1, U33.6 (REF)
unnamed: R72.1, U33.14 (RESET#)
unnamed: C155.1, C211.1, FB12.2, U33.4 (VPHY)
unnamed: C157.1, C212.1, FB14.2, U33.9 (VPLL)

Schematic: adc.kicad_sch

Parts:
C19, C20, C217, C218, C222, C249: 1u; SMD_0603
C22, C31, C216, C220: 2.2u; SMD_0603
C23, C24, C25, C27, C30, C219, C221, C223, C224, C225: 100n; SMD_0402
C163, C164, C165, C166, C167, C168: 100p; SMD_0402
C248: 10u; SMD_0805
R20, R93: 0; SMD_0402
R21: 33; SMD_0402
R91: 4.7k; SMD_0402
R92: 10k; SMD_0402
R97, R98, R99, R100: 49.9; SMD_0402
U8: LTC2292; QFN-64-1EP_9x9mm_Pitch0.5mm
U39: LP5907-3.0; SOT-23-5

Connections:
/3V3D: C25.1, C225.1, U8.32 (OVDD), U8.49 (OVDD); also elsewhere on the board
/3V8: C248.1, U39.1 (IN), U39.3 (EN); also elsewhere on the board
/ADC1+: R100.2; also elsewhere on the board
/ADC1-: R98.2; also elsewhere on the board
/ADC2+: R97.2; also elsewhere on the board
/ADC2-: R99.2; also elsewhere on the board
/ADC_CLK: R21.2, U8.8 (CLKA), U8.9 (CLKB); also elsewhere on the board
/ADC_VCMA: C216.1, C219.1, U8.61 (VCMA); also elsewhere on the board
/ADC_VCMB: C30.1, C31.1, U8.20 (VCMB); also elsewhere on the board
/fpga/ADC_OE1: U8.58 (~OEA); also elsewhere on the board
/fpga/ADC_OE2: U8.23 (~OEB); also elsewhere on the board
/fpga/ADC_SHDN1: U8.59 (SHDNA); also elsewhere on the board
/fpga/ADC_SHDN2: U8.22 (SHDNB); also elsewhere on the board
/fpga/D0: U8.43 (DA0); also elsewhere on the board
/fpga/D1: U8.44 (DA1); also elsewhere on the board
/fpga/D2: U8.45 (DA2); also elsewhere on the board
/fpga/D3: U8.46 (DA3); also elsewhere on the board
/fpga/D4: U8.47 (DA4); also elsewhere on the board
/fpga/D5: U8.48 (DA5); also elsewhere on the board
/fpga/D6: U8.51 (DA6); also elsewhere on the board
/fpga/D7: U8.52 (DA7); also elsewhere on the board
/fpga/D8: U8.53 (DA8); also elsewhere on the board
/fpga/D9: U8.54 (DA9); also elsewhere on the board
/fpga/D10: U8.55 (DA10); also elsewhere on the board
/fpga/D11: U8.56 (DA11); also elsewhere on the board
/fpga/OFA: U8.57 (OFA); also elsewhere on the board
/fpga/OFB: U8.40 (OFB); also elsewhere on the board
/fpga/adc/3V0: C24.1, C27.1, C222.1, C223.1, C224.1, C249.1, R20.2, R91.1, R93.2, U8.7 (VDD), U8.10 (VDD), U8.18 (VDD), U8.63 (VDD), U39.5 (OUT)
/fpga/adc/REFHA: C217.1, C220.1, C221.1, U8.3 (REFHA), U8.4 (REFHA)
/fpga/adc/REFHB: C19.1, C22.1, C23.1, U8.11 (REFLB), U8.12 (REFLB)
/fpga/adc/REFLA: C218.1, C220.2, C221.2, U8.5 (REFLA), U8.6 (REFLA)
/fpga/adc/REFLB: C20.1, C22.2, C23.2, U8.13 (REFHB), U8.14 (REFHB)
GND: C19.2, C20.2, C24.2, C25.2, C27.2, C30.2, C31.2, C163.1, C165.2, C166.1, C168.2, C216.2, C217.2, C218.2, C219.2, C222.2, C223.2, C224.2, C225.2, C248.2, C249.2, R92.2, U8.17 (GND), U8.31 (OGND), U8.50 (OGND), U8.64 (GND), U8.65 (PAD), U39.2 (GND); also elsewhere on the board
unnamed: C163.2, C164.1, R97.1, U8.1 (AINA+)
unnamed: C164.2, C165.1, R99.1, U8.2 (AINA-)
unnamed: C167.2, C168.1, R100.1, U8.16 (AINB+)
unnamed: C166.2, C167.1, R98.1, U8.15 (AINB-)
unnamed: R91.2, R92.1, U8.60 (MODE)
unnamed: R21.1, U8.21 (MUX)
unnamed: R93.1, U8.62 (SENSEA)
unnamed: R20.1, U8.19 (SENSEB)

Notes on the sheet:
2/3 VDD clock duty stabilizer 2s complement signed output This helped for better waveform
Important Note: ECS-TXO-3225MV is pure sin. Adc does not like sin i guess. Other ref designed used clipped more square like sin. That is why clock stabilizer is needed.

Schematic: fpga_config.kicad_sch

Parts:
C18, C252: 100n; SMD_0402
C170, C171, C187, C189, C190, C191, C192, C193, C197, C198, C199, C200, C201, C202, C203, C204, C250, C251: 470n; SMD_0402
C181: 100u; SMD_1210
C182, C184, C196: 47u; SMD_1206
C183, C185, C186, C188, C194, C195: 4.7u; SMD_0603
CON1: SD_Card_DM3BT; DM3BT-DSF-PEJS
D6: LED; Diode_0603
J2: Connector_02x08; PinHeader_2x8_P2.5mm
R10: DNP; SMD_0402
R14, R112, R117, R118: 4.7k; SMD_0402
R109: 1k; SMD_0402
R110, R114, R115: 0; SMD_0402
SW1, SW2: B3U-1000P; EVP-AWBA2A
U40: W25Q128JV; DFN-S-8-1EP_6x5mm_Pitch1.27mm

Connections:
/1V0: C181.1, C183.1, C184.1, C186.1, C187.1, C189.1, C191.1, C250.1; also elsewhere on the board
/1V8: C182.1, C185.1, C188.1, C190.1, C192.1, C193.1; also elsewhere on the board
/3V3D: C18.1, C170.1, C171.1, C194.1, C195.1, C196.1, C197.1, C198.1, C199.1, C200.1, C201.1, C202.1, C203.1, C204.1, C251.1, C252.1, CON1.4 (VDD), J2.13, J2.15, R10.2, R14.1, R110.1, R112.1, R117.1, R118.1, U40.3 (~WP(IO2)), U40.7 (~HOLD(IO3)), U40.8 (VCC); also elsewhere on the board
/fpga/CARD_DETECT: CON1.9 (CARD_DETECT1); also elsewhere on the board
/fpga/INIT_B: R117.2; also elsewhere on the board
/fpga/M0: R110.2; also elsewhere on the board
/fpga/M1: R114.1; also elsewhere on the board
/fpga/M2: R10.1, R115.1; also elsewhere on the board
/fpga/PIN1: J2.11; also elsewhere on the board
/fpga/PIN2: J2.10; also elsewhere on the board
/fpga/PIN3: J2.8; also elsewhere on the board
/fpga/PIN4: J2.12; also elsewhere on the board
/fpga/PIN5: J2.9; also elsewhere on the board
/fpga/PIN6: J2.7; also elsewhere on the board
/fpga/PIN7: J2.6; also elsewhere on the board
/fpga/PIN8: J2.4; also elsewhere on the board
/fpga/PIN9: J2.2; also elsewhere on the board
/fpga/PIN10: J2.5; also elsewhere on the board
/fpga/PIN11: J2.3; also elsewhere on the board
/fpga/PIN12: J2.1; also elsewhere on the board
/fpga/PROG_B: R112.2, SW2.1; also elsewhere on the board
/fpga/RESET: R14.2, SW1.1; also elsewhere on the board
/fpga/SD_CLK: CON1.5 (CLK); also elsewhere on the board
/fpga/SD_CMD: CON1.3 (CMD); also elsewhere on the board
/fpga/SD_DAT0: CON1.7 (DAT0); also elsewhere on the board
/fpga/SD_DAT1: CON1.8 (DAT1); also elsewhere on the board
/fpga/SD_DAT2: CON1.1 (DAT2); also elsewhere on the board
/fpga/SD_DAT3: CON1.2 (CD/DAT3); also elsewhere on the board
/fpga/SPI_CLK: U40.6 (CLK); also elsewhere on the board
/fpga/SPI_CS: R118.2, U40.1 (~CS); also elsewhere on the board
/fpga/SPI_MISO: U40.2 (DO(IO1)); also elsewhere on the board
/fpga/SPI_MOSI: U40.5 (DI(IO0)); also elsewhere on the board
/fpga/USER_LED: R109.1; also elsewhere on the board
GND: C18.2, C170.2, C171.2, C181.2, C182.2, C183.2, C184.2, C185.2, C186.2, C187.2, C188.2, C189.2, C190.2, C191.2, C192.2, C193.2, C194.2, C195.2, C196.2, C197.2, C198.2, C199.2, C200.2, C201.2, C202.2, C203.2, C204.2, C250.2, C251.2, C252.2, CON1.6 (VSS), CON1.10 (CARD_DETECT2), CON1.11 (SHELL), D6.1 (K), J2.14, J2.16, R114.2, R115.2, SW1.2, SW2.2, U40.4 (GND), U40.9 (EP); also elsewhere on the board
unnamed: D6.2 (A), R109.2

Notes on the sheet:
VCCBRAM
in SPI Flash mode, JTAG can be used.
VCCINT
32 is not supported by vivado openFPGALoader is needed. 128 is same price supported and more memory is available.
VCCAUX
VCCO_0
Mode M[2:0] Master SPI 001 JTAG 101
VCCO

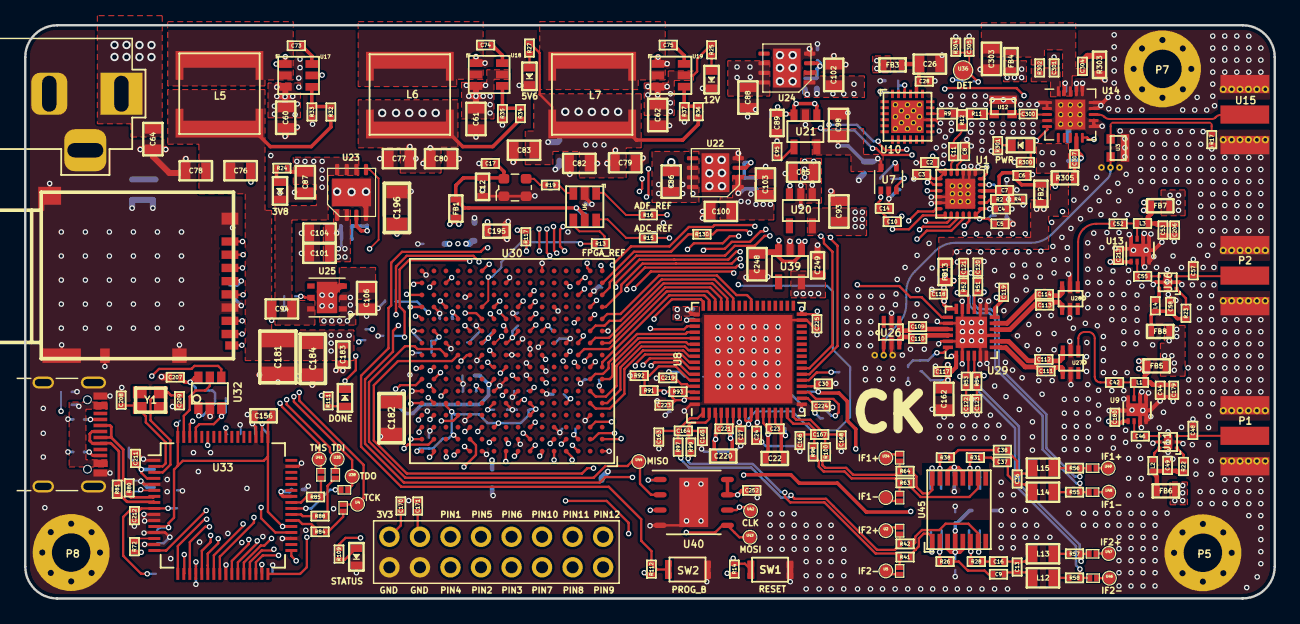
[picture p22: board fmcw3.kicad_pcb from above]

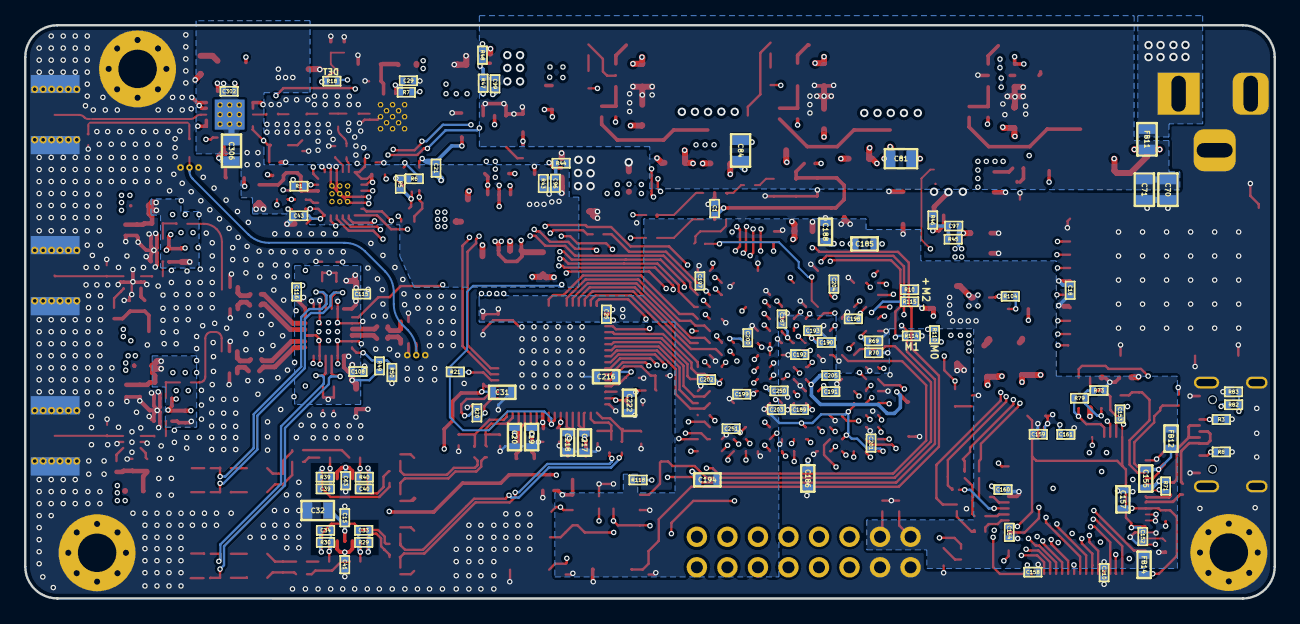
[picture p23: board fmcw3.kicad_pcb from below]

Board: 6 copper layers, 104.0 x 47.7 mm, 382 parts (101 on the bottom side), 258 nets.

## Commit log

2025-05-01 Init commit
    [adc-2023-03-24-11-11-22.sch, adc.kicad_sch, fmcw3-2023-03-24-11-11-22.sch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]
2025-05-01 Leds are added to schematic netlist is generated will be placed on pcb
    [power.kicad_sch]
2025-08-12 3 leds are added design is checked. Schematic pin name corrected
    [fmcw3.kicad_sch, tx.kicad_sch]
2025-08-12 Artix 7 Mode pin 2 was connected to 3.3 and Gnd. It is corrected. It is in JTAG mode for now. I will add dip switch
    [fpga.kicad_sch]
2025-08-20 Reset button is added. Detout is connected to an adc pin of fpga. Unused pad is deleted. Pins are check. Notes are added on pcb side. No problem related error drc excluded
    [fmcw3.kicad_sch, fpga.kicad_sch, tx.kicad_sch]
2025-08-20 LO trace is soft bended for continuous 50 ohm
2025-08-21 ADC differential length is matched as much as possible for better phase
2025-08-21 ADC path correction
2025-08-21 CST Studio simulation is made and 50 ohm line is 0.169mm and 0.14mm spacing is required for same 17dB coupling as in oshpark design. Rf traces are corrected with 0.169mm. Directional coupler will be 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
2025-08-22 I have designed 0.17mm directional coupler and placed on pcb. Further improvements for better layout will be done
    [tx.kicad_sch]
2025-08-22 0.17mm is correctly simulated on cst studio. It is implemented on pcb
2025-11-01 fpga usb clkout pin and one more pin is changed
    [fpga.kicad_sch]
2025-11-02 fpga pin change pdf update
2025-12-18 usb rd and clkout pins are routed already. Space to gnd on same layer from rf paths will be added for 50 ohm microstrip line
2025-12-31 balun must be 50:50 since adl5802 inputs are diff 50 ohm. But 0.17 0.17 is making 100 ohm
2026-01-01 0.1 spacing is corrected on board setup and net class rules section. It does not have any error now
2026-01-01 IMPORTANT FIX: ADL5802 if output is 200ohm so diff pull ups must be 100 not 50. I have corrected that
    [mixer.kicad_sch]
2026-01-01 Important comment is added to the pcb for rf lines. Follow those rules and correct design
2026-01-02 vias are placed at same rf traces and copper pour areas
2026-01-04 corrected differential rf traces and checked vias. drc has no error
2026-01-04 rf traces vias are completed. It is done. I will do last checks
2026-01-04 pcb design is checked with drc on schematic and pcb. It look good
2026-01-04 Clock buffer path cap changed to resistor.
    [fmcw3.kicad_sch]
2026-01-04 Resistor value is changed to 0 ohm
    [fmcw3.kicad_sch]
2026-01-04 production files are generated
    [bom.csv, designators.csv, positions.csv]
2026-01-06 after a few minor cap replacement desing is regenerated and sent for production.
    [positions.csv]
2026-03-01 component name correction
    [fmcw3.csv, power.kicad_sch]
2026-05-21 final corrections is done. Working!
    [adc.kicad_sch, fmcw3.kicad_sch, if.kicad_sch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]
2026-05-22 I increased the gap between voltage pours and also corrected signals cutting copper pour. Also not connected gnd occured in some layers are corrected with no copper zoens
    [adc.kicad_sch, bom.csv, fpga.kicad_sch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]
2026-05-22 Minor changes are done. Pcb is ready. Production file is added
    [bom.csv, designators.csv, if.kicad_sch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]
2026-05-24 clock buffer and txco source is changed. Clock is clipped sin and fanout says cmos square out but it is better anyways. Also traces are 50 ohm as well. Copper pours other minor thinks are changed as 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
    [adc.kicad_sch, fmcw3.csv, fmcw3.kicad_sch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]
2026-05-24 changes are pushed
    [fmcw3.kicad_sch]
2026-05-26 final changes
    [fmcw3.kicad_sch, if.kicad_sch, mixer.kicad_sch]
2026-05-30 hardware changes
    [clock.kicad_sch, fmcw3.kicad_sch, fpga.kicad_sch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]
2026-05-31 schematic is updated pcb is almost done
    [fmcw3.kicad_sch, fpga.kicad_sch, if.kicad_sch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]
2026-05-31 lt6232 implementation is done. Keep out area around opamp will be added
    [fmcw3.kicad_pcb]
2026-06-02 vcom trace width is changed
    [fmcw3.kicad_pcb]
2026-06-02 checks are done.
    [fmcw3.kicad_pcb, power.kicad_sch]
2026-06-02 regulator cooper pours are continuous it is checked. gnd vias will be added
    [fmcw3.kicad_pcb]
2026-06-04 lt6232 is done. I push latest updates
    [fmcw3.kicad_pcb, fmcw3.kicad_sch]
2026-06-04 3.3v regulator is upgraded
    [fmcw3.kicad_pcb, power.kicad_sch]
2026-06-06 lt6232 is done with vias and copper pours are checked
    [adc.kicad_sch, clock.kicad_sch, fmcw3.kicad_pcb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]
2026-06-26 DNP components are deleted
    [fmcw3.kicad_pcb, mixer.kicad_sch, power.kicad_sch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]
2026-06-30 pcb is checked dnp is deleted copper pours are checked
    [fmcw3.kicad_pcb, fmcw3.kicad_sch, opamp_amp.kicad_sch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]
2026-07-03 minor corrections
    [adc.kicad_sch, fmcw3.kicad_pcb, fmcw3.kicad_sch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]
2026-07-04 production file is generated
    [bom.csv, designators.csv, fmcw3.kicad_pcb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]
2026-07-07 final version ready for order
    [fmcw3.kicad_pcb, positions.csv]
2026-08-04 100t changes design is working tested on a real hardware. Main branch is verified
    [fmcw3.kicad_pcb, fpga.kicad_sch, opamp_amp.kicad_sch]
